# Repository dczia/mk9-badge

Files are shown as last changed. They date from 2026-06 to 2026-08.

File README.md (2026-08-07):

```
___  ____     _____  ______           _            
|  \/  | |   |  _  | | ___ \         | |           
| .  . | | __| |_| | | |_/ / __ _  __| | __ _  ___ 
| |\/| | |/ /\____ | | ___ \/ _` |/ _` |/ _` |/ _ \
| |  | |   < .___/ / | |_/ / (_| | (_| | (_| |  __/
\_|  |_/_|\_\\____/  \____/ \__,_|\__,_|\__, |\___|
                                         __/ |     
                                        |___/      
-------------------------------------------------
D C Z I A  ----------  2 0 2 6
```

DCZia Presents: The MK9 Badge

It blinks. It types. You can wear it around your neck and then set it on your desk and actually use it\*.

\* _Desk productivity not guaranteed. DCZia assumes no responsibility for keys accidentally sent during badge parties. Consult your keyboard layer documentation before operating heavy machinery._

---

## About

The **MK9** is a fully functional **3×3 mechanical macropad badge**. Nine real mechanical switches, per-key RGB lighting, ambient underglow, an accelerometer that actually does something interesting, SAO support, and CircuitPython firmware out of the box — all in a package sized to hang around your neck at DEF CON and survive the week.

---

## Specs

**Keys**
- 9× mechanical switches in a 3×3 grid — standard MX footprint, swap keycaps as you please
- Ships with translucent blue keycaps
- Full N-key rollover USB HID keyboard when plugged into a computer

**Lighting**
- 9× WS2812B per-key RGB LEDs — one under each switch
- 6× SK6812 side-firing LEDs — edge-mounted for ambient underglow out the sides

**Brains & Sensors**
- RP2040 microcontroller
- 3-axis accelerometer — tilt-reactive lighting, shake to change patterns
- 2× SAO connectors (standard 6-pin, I2C + 2 GPIO each) — expand with the badge add-on ecosystem

**Power & I/O**
- USB-C — power and data
- 3× AAA battery pack — run it untethered
- Power switch for battery mode
- Reset button + BOOTSEL button for easy firmware flashing

**Firmware**
- Ships with CircuitPython firmware
- QMK-compatible hardware — reflash and run it as a full QMK macropad

---

## What It Does Out of the Box

On boot: a rainbow diagonal wipe sweeps across the keys and backlights. Any keypress skips it.

Once running:
- Background light patterns cycle across all 15 LEDs — rainbow wave, breathing pulse, or sparkle
- Pressing a key sends a colour ripple expanding outward from that key through all the LEDs
- Tilt the badge to shift the colour palette; shake it to switch patterns
- Plug into a computer and it shows up as a numpad (7–9 / 4–6 / 1–3 layout)

---

## Repository

```
mk9-badge/
├── buildguide.md — badge assembly, flashing, and troubleshooting
├── hardware/   — KiCad design files, BOM, fabrication outputs
└── software/   — MicroPython firmware
```

- [Build Guide →](buildguide.md) — assembly, battery installation, flashing, and troubleshooting
- [Hardware →](hardware/README.md) — schematics, PCB layout, drill files, BOM
- [Software →](software/README.md) — firmware architecture, pinout, library requirements, flashing instructions

**Fabrication outputs**:
- [PCB layer plot](hardware/output/mk9-badge.pdf)
- [PTH drill map](hardware/output/mk9-badge-PTH-drl_map.pdf)
- [NPTH drill map](hardware/output/mk9-badge-NPTH-drl_map.pdf)

---

## Programming / Updating

The badge runs [CircuitPython](https://circuitpython.org). To update the firmware:

1. Hold **BOOTSEL** while plugging the badge into your computer — it mounts as `RPI-RP2`.
2. Drag the CircuitPython `.uf2` onto the drive. It reboots as `CIRCUITPY`.
3. Copy the `lib/` folder contents to `CIRCUITPY/lib/` (see [software/README.md](software/README.md) for the library list).
4. Copy all `.py` files from `software/` to the root of `CIRCUITPY`.

The badge restarts automatically. If it gets into a weird state, delete everything on `CIRCUITPY` and start fresh — it won't brick.

Want to run QMK instead? The hardware is fully compatible; QMK setup instructions will be posted separately.

**Recommended IDEs:** Visual Studio Code with the [CircuitPython extension](https://marketplace.visualstudio.com/items?itemName=ms-python.python), or [Thonny](https://thonny.org). A Commodore 64 with a serial adapter also works but is left as an exercise for the reader.

---

## Open Source

DCZia is committed to open source hardware and software. All design files and firmware are publicly available.

- **Live CAD (OnShape):** [View the design](https://cad.onshape.com/documents/36884624fbe35c16a5af61a7/w/233227193d278274727a44c3/e/ea987b4b53c4648fa3dc84b6)

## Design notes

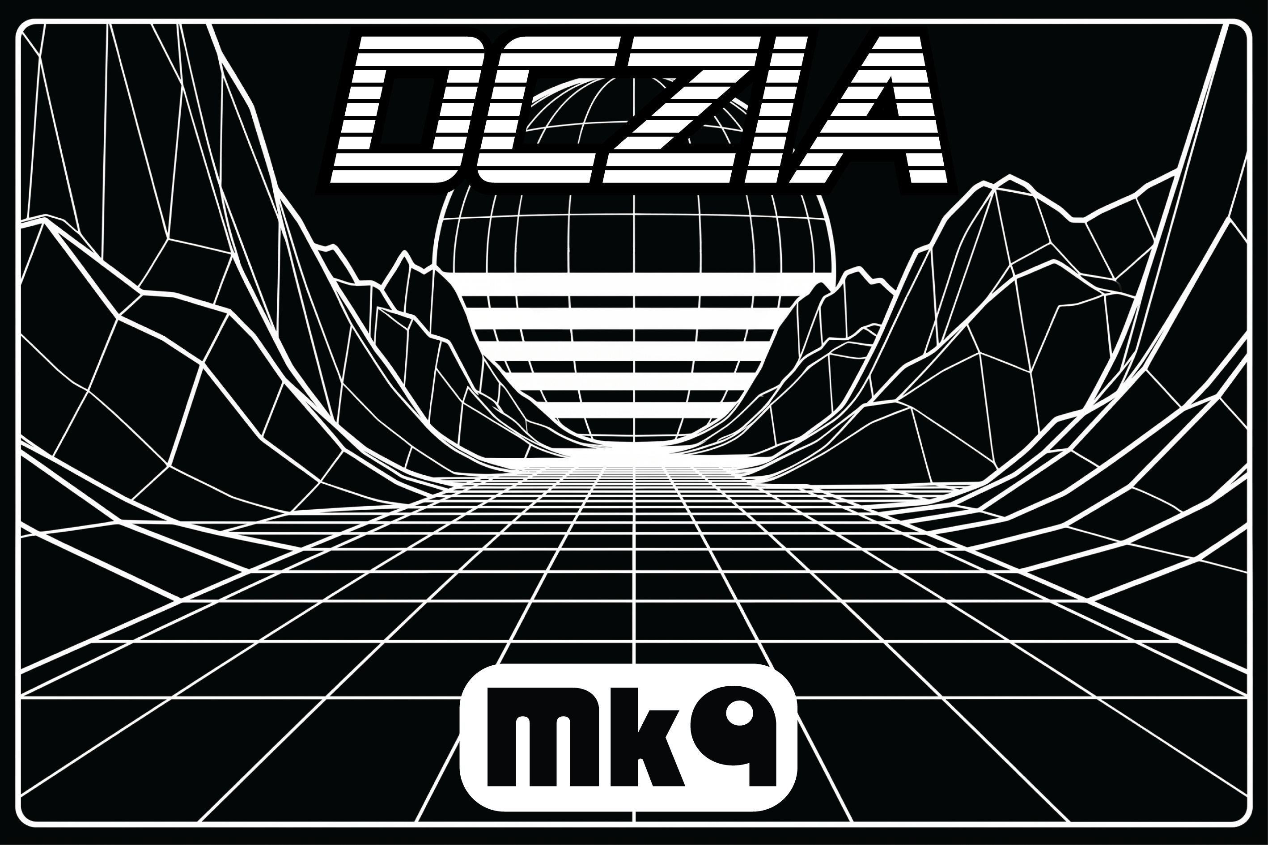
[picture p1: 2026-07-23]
hardware/images/SAO-Adapter.png

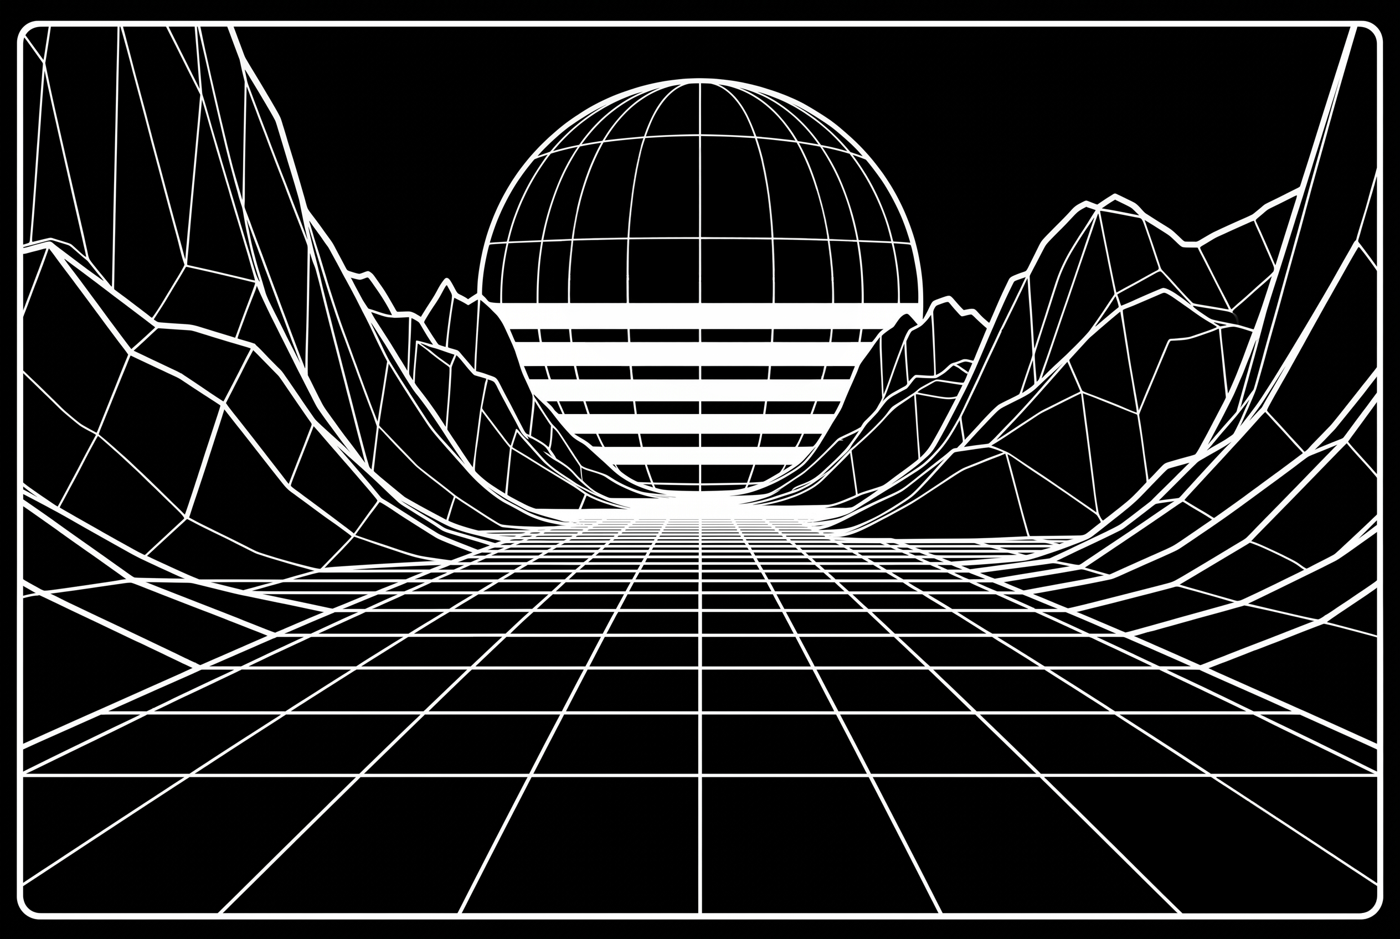
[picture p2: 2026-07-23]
hardware/images/cyberscape background.png

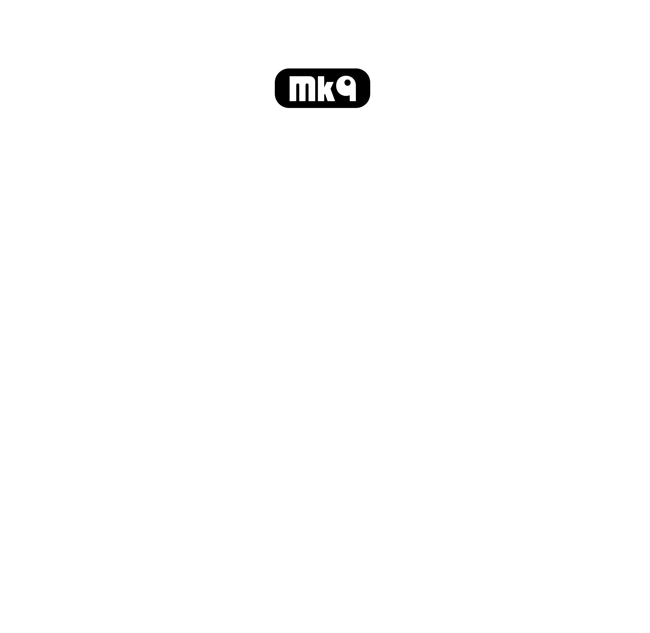
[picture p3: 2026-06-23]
hardware/images/Board_Silk.png

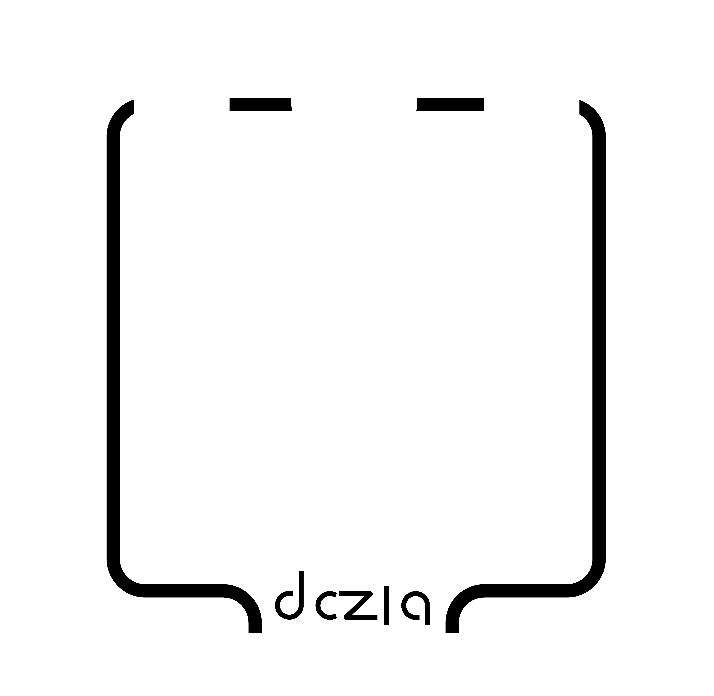
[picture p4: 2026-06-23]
hardware/images/Board_Copper.png

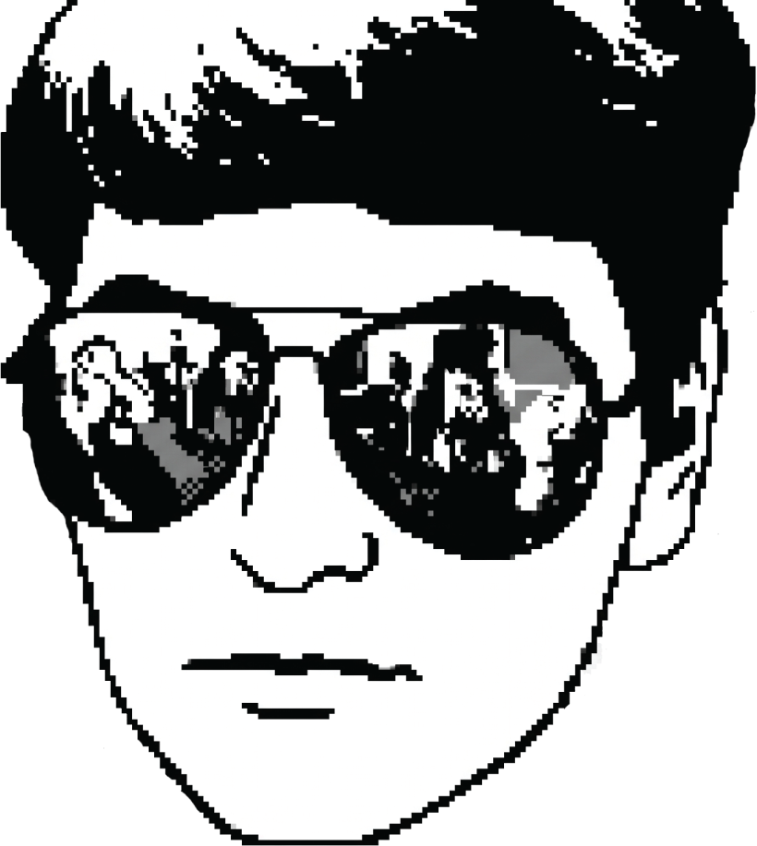
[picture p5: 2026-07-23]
hardware/images/bob.png

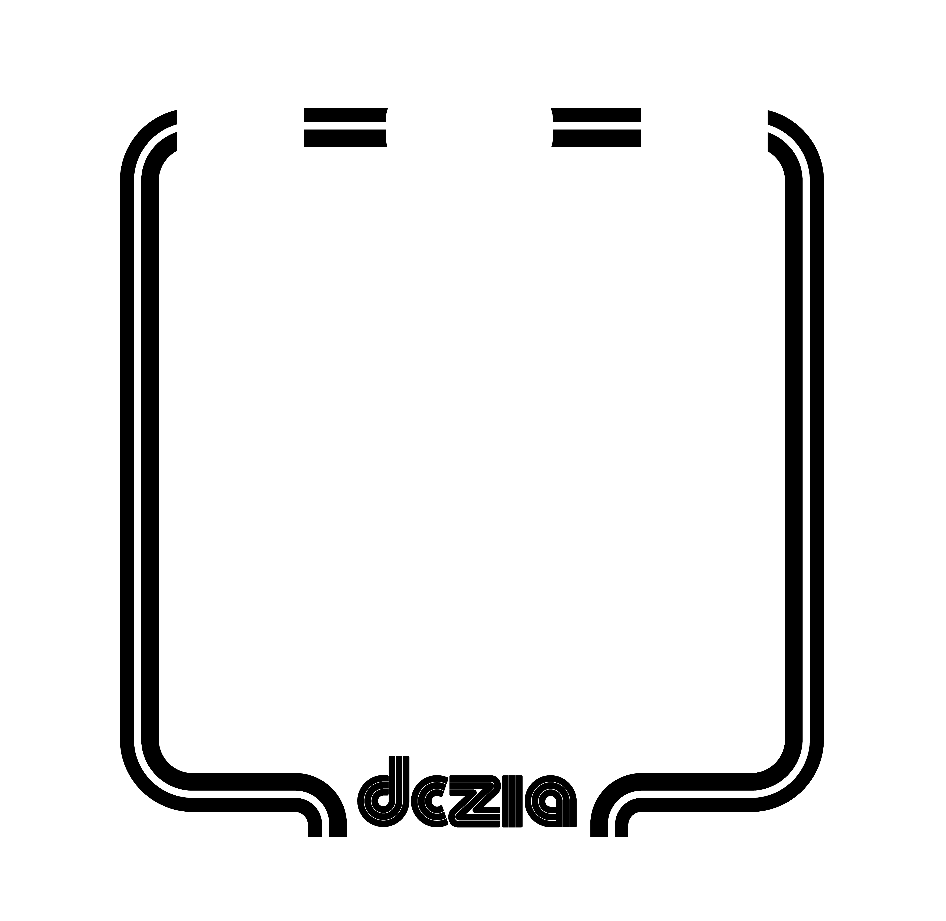
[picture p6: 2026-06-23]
hardware/images/Board_Mask.png

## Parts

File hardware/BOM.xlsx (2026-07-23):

Reference | Feeder | Value | Footprint | Part Number | Distributor | Distributor Part | Datasheet | Qty | Cost Each | Qty Ordered | QOH | Notes
C3,C5,C6,C8-C12,C15-C20 | 6 | 0.1uF | 0603 |  |  |  | ~ | 14 | 0.004 | 0 | 2500
C4,C7,C13,C14 | 7 | 1uF | 0603 |  |  |  | ~ | 4 | 0.004 | 0 | 3500
C1,C2 | 8 | 15pF | 0603 |  |  |  | ~ | 2 | 0.004 | 0 | 3500
D2-12 | 9 | D_Schottky | SOD-123 |  | Digikey | 3757-SS0540_R1_00001DKR-ND | https://www.panjit.com.tw/upload/datasheet/SS0520_SERIES.pdf | 2 | 0.11 | 0 | 2500
D13-21 | 23 | WS2812B | LED_SMD:LED_WS2812B_PLCC4_5.0x5.0mm_P3.2mm |  | Aliexpress | https://www.aliexpress.us/item/2251832628463811.html | https://cdn-shop.adafruit.com/datasheets/WS2812B.pdf | 9 | 0.07 | 0 | 2000
D22-27 | 22 | SK6812 |  |  | Aliexpress |  |  | 6 | 0.1 | 1000 | 0
D1 |  | TVS |  | SP0502BAHTG | Mouser | 576-SP0502BAHTG | https://www.littelfuse.com/assetdocs/tvs-diode-array-spasp050xba-lead-free-green-datasheet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 | 0 | 0.383 |  |  | Optional stuffing
J1 |  | USB-C | Connector_USB:USB_C_Receptacle_HCTL_HC-TYPE-C-16P-01A |  | Aliexpress | https://www.aliexpress.us/item/3256805324706422.html | https://www.lcsc.com/datasheet/lcsc_datasheet_2211161000_HCTL-HC-TYPE-C-16P-01A_C2894897.pdf | 1 | 0.19 | 150 | 100
R1,R7 | manual | 1k | 0603 |  |  |  | ~ | 2 | 0.001 | 0 | 4500
R6,R8 | 1 | 10k | 0603 |  |  |  | ~ | 2 | 0.001 | 0 | 4500
R2,R3 | 5 | 5.1k | 0603 |  |  |  | ~ | 2 | 0.001 | 0 | 4500
R4,R5 | 2 | 27R | 0603 |  |  |  | ~ | 2 | 0.001 | 0 | 4500
R9 | manual | 10R | 0603 |  |  |  | ~ | 1 | 0.001 | 0 | 4500
R10,R11 | 3 | 4.7k | 0603 |  |  |  |  | 2 | 0.001 | 5000 | 0
S1,S3 | after | SPST Push w/boss | Button_Switch_SMD:SW_SPST_EVQP7C | EVQ-P7C01P | Digikey | P16765CT-ND | https://api.pim.na.industrial.panasonic.com/file_stream/main/fileversion/245500 | 2 | 0.20204 | 300 | 0
S2 | after | SW_SPDT | lib_fp:SW_SPDT_CK-JS102011SAQN | JS102011SAQN | Digikey | 401-1999-1-ND | https://ckswitches.com/media/1422/js.pdf | 1 | 0.6032 | 150 | 0
S4-12 |  | CherryMX Blue |  |  | Aliexpress |  |  | 9 | 0.1 | 1000 | 0
U3 | 10 | NCP115ASN330T2G | Package_TO_SOT_SMD:SOT-23-5 | NCP115ASN330T2G | Digikey | NCP115ASN330T2G | https://www.onsemi.com/pdf/datasheet/ncp115-d.pdf | 1 | 0.0677 | 0 | 2500
U2 | 30 | RP2040 | Package_DFN_QFN:QFN-56-1EP_7x7mm_P0.4mm_EP3.2x3.2mm | SC0914(7) | Mouser | 358-SC09147 | https://datasheets.raspberrypi.com/rp2040/rp2040-datasheet.pdf | 1 | 0.8 | 0 | 1000
U4 | after | W25Q128JVSIM |  |  | Digikey | W25Q128JVSIM-ND | https://www.winbond.com/resource-files/W25Q128JV%20RevI%2008232021%20Plus.pdf | 1 | 2.51556 | 133 | 0
U1 | manual | GSDA213 | Kionix_LGA-12_2x2mm_P0.5mm_LayoutBorder2x4y | GSDA213 | Digikey | 4786-GSDA213TR-ND | https://goodarksemi.com/docs/datasheets/mems/GSDA213_SDS.pdf | 1 | 0.6595 | 150 | 0
X1,X2 |  | Badgelife_sao_connector_v169bis | lib_fp:Badgelife-Shitty-v1.69bis | VIRTUAL |  |  |  | 2
Y1 | manual | Crystal | Crystal:Crystal_SMD_3225-4Pin_3.2x2.5mm | ABM8-272-T3 | Digikey | 535-ABM8-272-T3DKR-ND | https://abracon.com/datasheets/ABM8-272-T3.pdf | 1 | 0.4085 | 150 | 0
 |  | Key caps |  |  |  |  |  | 9 | 0.19 | 1500
` |  | Battery boxes |  |  |  |  |  | 1 |  | 125
 |  | PCB |  |  |  |  |  | 1 |  | 200
 |  | Batteries |  |  | Amazon |  |  | 3 | 0.15 | 300
 |  | Badge Run, units | 120

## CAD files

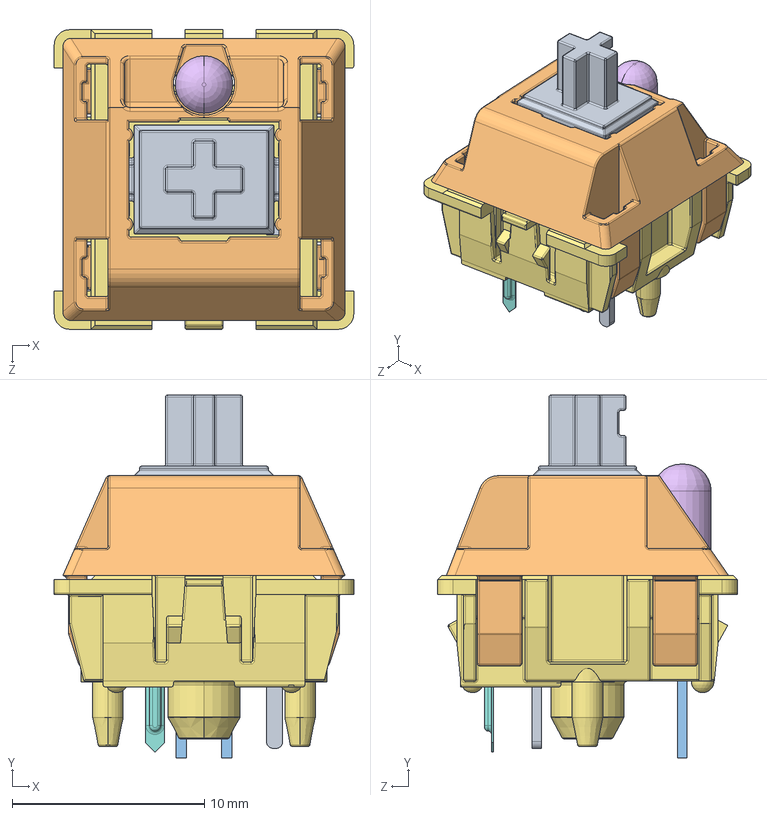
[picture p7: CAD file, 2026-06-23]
hardware/3d/MX.STEP
15.6 x 18.9 x 15.6 mm
MX ? ?? x 2
MX? ??LED
MX? ?? ??___
??___

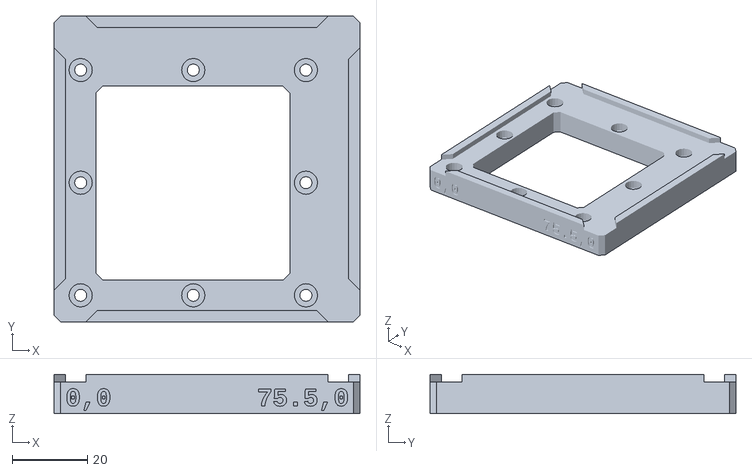
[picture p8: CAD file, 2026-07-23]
hardware/output/pcb_holder.stl
81.5 x 81.5 x 10.4

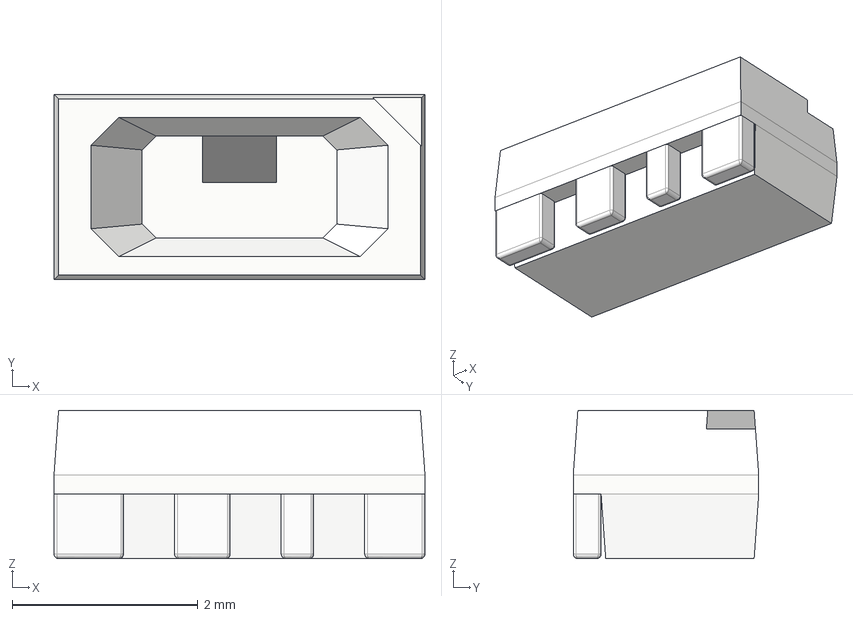
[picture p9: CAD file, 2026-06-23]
hardware/3d/sk6812side v0.step
4.00 x 2.00 x 1.60 mm

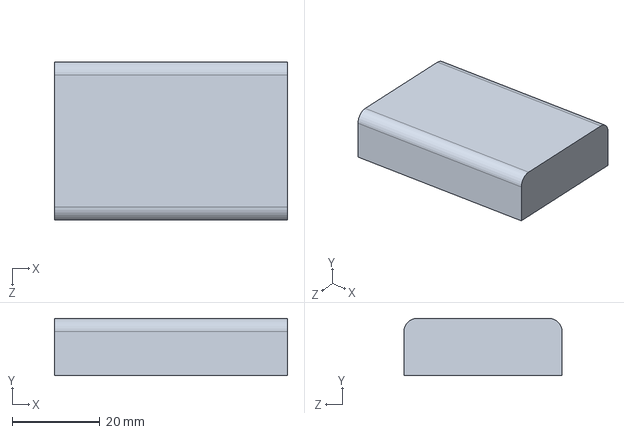
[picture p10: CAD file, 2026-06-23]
hardware/3d/3AAA Battery Box - Flying Leads.SLDPRT
53.0 x 13.0 x 36.0 mm

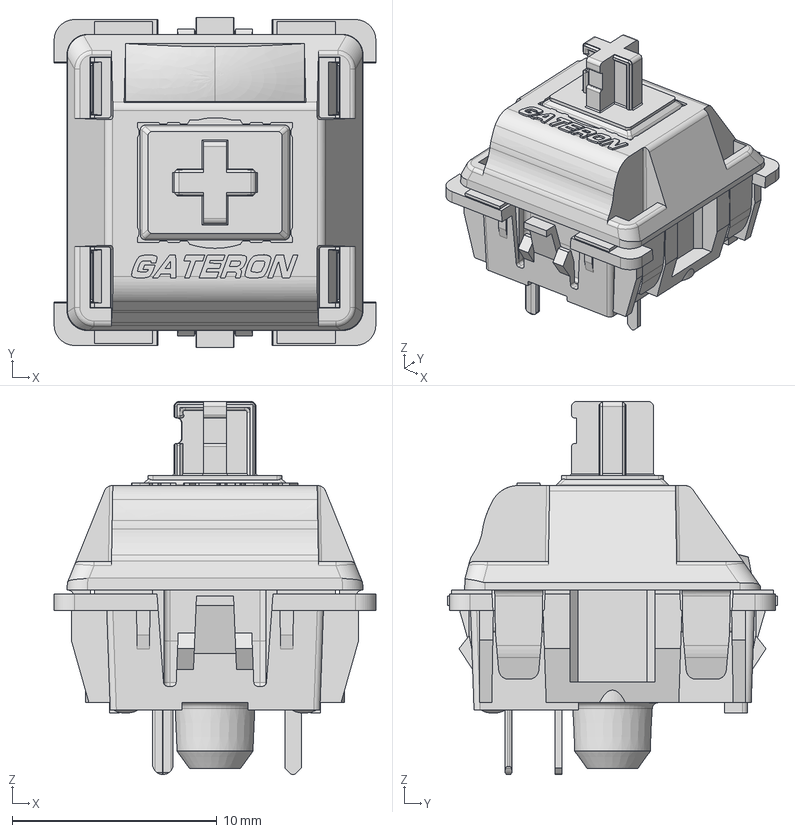
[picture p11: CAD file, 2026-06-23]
hardware/3d/G_PRO_3.0_Switch_KS-9E10B055NN-Y51.stp
15.7 x 16.1 x 18.2 mm

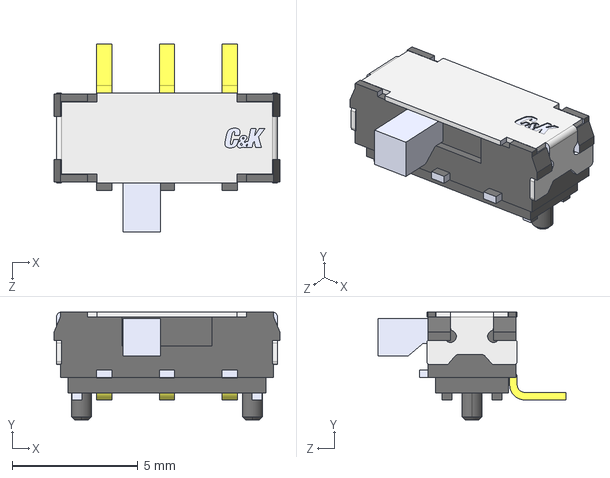
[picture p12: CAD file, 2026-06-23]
hardware/3d/JS102011SAQN.stp
9.00 x 4.30 x 7.50 mm

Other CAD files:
hardware/3d/G_PRO_3.0_Color.STEP

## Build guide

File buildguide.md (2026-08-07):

## TL;DR Instructions

1. Take the diffuser and back case off the badge using the included allen wrench
2. Solder on the keyswitches
3. Solder on the battery holder.
4. Reasseble the diffuser + case
5. Flash the badge with the u2f firmware from github / link can be found on www.dczia.net

## Intro

Thanks for purchasing the 2026 DCZia “mk9” badge! This badge is a throwback to our earlier keygrid badge from 2018. The badge features 9 mechanical MX style key switches (Gateron Blues), an accelerometer for sensing movement and adjusting the light patterns, and the badge can function as a usb keyboard / macro pad. By default the badge will output the keystrokes 1-9 like a num pad, but you can modify the code or flash QMK to use a full programmable macropad if you want. The badge is powered by an RPI 2040 microcontroller, with a 16mb flash module for expansion. An accelerometer is included as well.

## Building

The badge is shipped with the frosted diffuser, and back case pre installed. You will need to remove these pieces to safely solder on the keyswitches. Use the included allan key to disassemble the case.

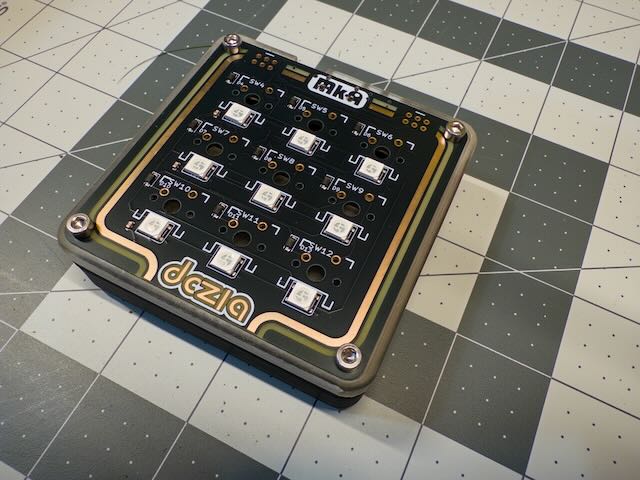
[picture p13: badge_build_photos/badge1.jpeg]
BuildPhoto1 Badge1


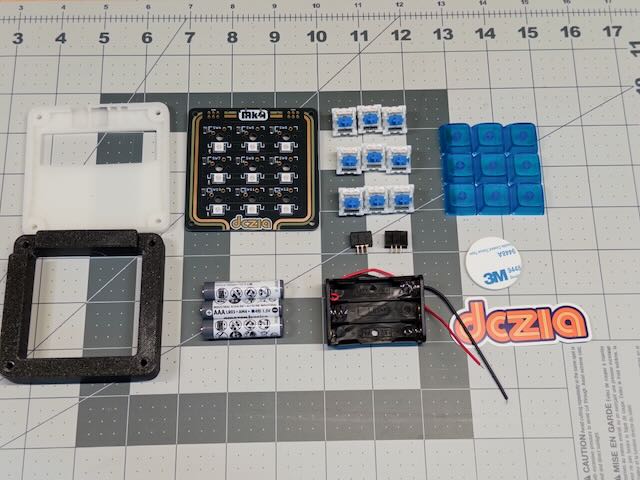
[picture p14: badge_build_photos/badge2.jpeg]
BuildPhoto2 Badge2


Now you can install one keyswitch, and solder it onto the board. Please go slow, and try to line up the switch carefully. Sometimes some tape can be useful to keep the switch in place. Solder on all 9 key switches.

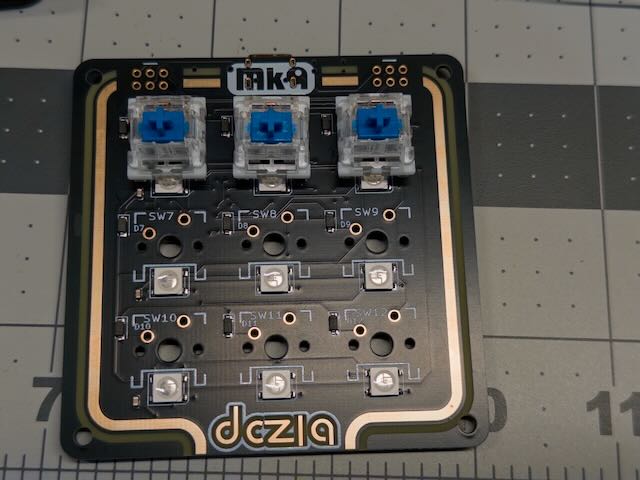
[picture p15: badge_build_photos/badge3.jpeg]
BuildPhoto3 Badge3

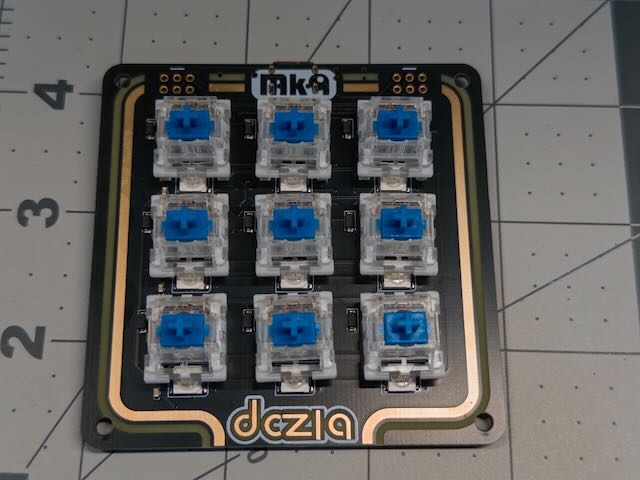
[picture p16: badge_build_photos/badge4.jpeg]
BuildPhoto4 Badge4

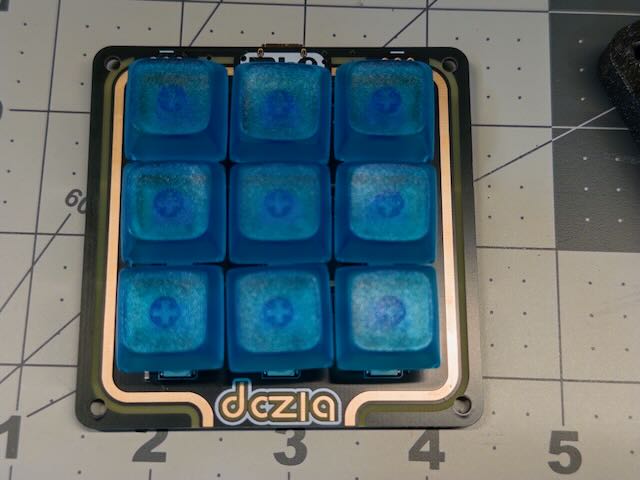
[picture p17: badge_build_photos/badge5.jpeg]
BuildPhoto5 Badge5


Reassemble the case, and gently screw it back together. 

Next solder on the battery pack. The red wire will go to the “+” pad on the back of the pcb, and the black wire to the “-” pad. The badge can be fully powered over USB C if you do not wish to attach the battery pack.

Next, using the round double sticky tape, apply it to the battery pack, and then stick it to the frosted diffuser. Press gently on the battery pack for about 15 seconds to make sure you have good adhesion.

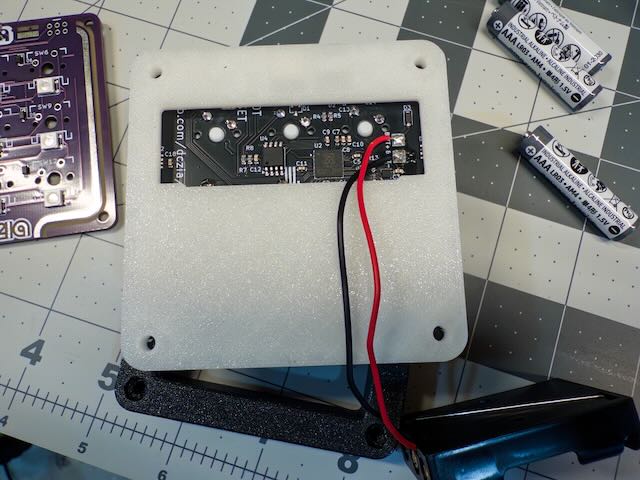
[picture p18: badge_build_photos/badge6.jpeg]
BuildPhoto5 Badge6


Finally install the batteries. The badge is pre-flashed with firmware and should be good to go!

Short press a key to see a light flash, long press a key to change the color theme. Tilt for accelerometer to affect the lights.

## Manual Flashing (Only if you want to update or write new code)

The badge is pre flashed, but you can run the script in the repo to flash the badge, or we will have a U2F uploaded which you can use as well.
Goto www.dczia.net, and click on the badge to be taken to the Github page for this project. Download the release which will have the source code, and a u2f file. Plug the badge into your computer and hold down the “Boot” button on the badge while plugging it in. You will need a pen or toothpick to press in the switch while plugging in the USB C cable. This will place the badge into bootloader mode. A usb drive should appear on your machine if you are using something common (Win / Mac) or if you don’t have an automounter and you are running linux, you can probably figure out how to mount the device as a drive. Drag the U2F file over to this drive. It will disconnected as soon as the transfer completes and the badge should reboot and begin showing some blinky lights!

## Badge Manual

Pressing any of the 9 keys will flash that keyswitch momentarily. Long pressing on one of the 9 keys will change the light themes. The accelerometer will allow you to tilt the badge in any of the light themes to affect the light pattern. Pressing any of the keys while plugged into usb c will output the keystroke 1-9. 

## Troubleshooting

*When i tilt my badge nothing happens?*

Some of the accelerometers may have gotten placed a bit off the pads. Find hamster for help, or if you have a hot air station, mask around the U1? part with kapton tape, and heat it gently while holding it down with some tweezers to realign to the pads. 

*Not all the keys are working?*

Re-check your solder connections on each switch

*The badge caught fire!*

The badge should only be powered by 3x AA batteries or USB-C. Please do not use car batteries, 120V AC, or small nuclear reactors to power the badge.

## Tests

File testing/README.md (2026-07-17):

# Hardware Tester

Self-contained hardware test fixture for the MK9 badge. Copy `code.py` to the root of `CIRCUITPY` (replacing the production firmware) to run the tests.

## What It Tests

### LEDs
All 15 LEDs (9 key + 6 backlight) cycle through **red → green → blue** continuously:
- Each color holds for **0.5 s**
- A directional wipe sweeps the next color across all LEDs over **0.5 s**
- Total: **1 second per color**

### Key Matrix
Press any key — its **LED fast-flashes red → green → blue** as long as the key is held, and is excluded from the background wipe until released. All 9 keys can be held simultaneously to verify N-key rollover. Every press/release is also logged to the serial console (`key N down` / `key N up`). Expected LED for each key:

```
key 0 (C0R0) → LED 0    key 1 (C1R0) → LED 1    key 2 (C2R0) → LED 2
key 3 (C0R1) → LED 3    key 4 (C1R1) → LED 4    key 5 (C2R1) → LED 5
key 6 (C0R2) → LED 6    key 7 (C1R2) → LED 7    key 8 (C2R2) → LED 8
```

### Accelerometer
The wipe always sweeps toward whichever edge is tilted down, decided when a new wipe starts:

| Axis reading | Meaning | Direction |
|---|---|---|
| X < 0 | Tilted left | Right → Left |
| X > 0 | Tilted right | Left → Right |
| Y < 0 | Top edge down | Bottom → Top |
| Y > 0 | Bottom edge down | Top → Bottom |
| Flat (both axes < 1 m/s²) | — | Holds last direction |

Tilt the badge and watch the wipe direction change on the next colour transition.

If the accelerometer library/sensor is missing at boot, or a read fails at runtime, the tester stops the colour-cycle test and instead flashes all LEDs solid **red, red, red, blue, green** (repeated) at 0.3 s/color, with no wipe, as a fault indicator.

### Serial Output
Connect a serial terminal to see:
- A boot message reporting whether the accelerometer initialized OK
- Accelerometer X/Y/Z readings printed once per second (or `accel: not available` if the sensor is down)
- `key N down` / `key N up` for every key press/release

## Libraries Required

Beyond CircuitPython built-ins (`board`, `busio`, `time`, `keypad`), copy these from the Adafruit CircuitPython Bundle into `lib/`:

| Library | Notes |
|---|---|
| `neopixel.mpy` | LED driver |
| `adafruit_msa3xx.mpy` | Accelerometer driver |
| `adafruit_bus_device/` | I2C helper — dependency of `adafruit_msa3xx` |
| `adafruit_register/` | Register access helper — dependency of `adafruit_msa3xx` |

If the accelerometer library is missing or the sensor doesn't respond, the tester falls back gracefully — LEDs and keys still work, but the LEDs switch to the red/red/red/blue/green fault-flash pattern described above instead of the normal colour cycle.

## Restoring Production Firmware

After testing, copy all files from `software/` back to the root of `CIRCUITPY` (including `boot.py`).

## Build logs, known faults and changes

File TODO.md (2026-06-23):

# MK9 Badge Hardware TODO

- [X] Add pull-up resistors on I2C lines
- [ ] Consider pullups for the accel
- [X] Add reset circuit
- [ ] Verify SK6812 pinouts
- [ ] Update flash footprint
- [ ] Update SPST footprints
- [X] Sidefire footprints
- [ ] libfp
- [ ] artwork
- [ ] order 4.7k resistors 0603

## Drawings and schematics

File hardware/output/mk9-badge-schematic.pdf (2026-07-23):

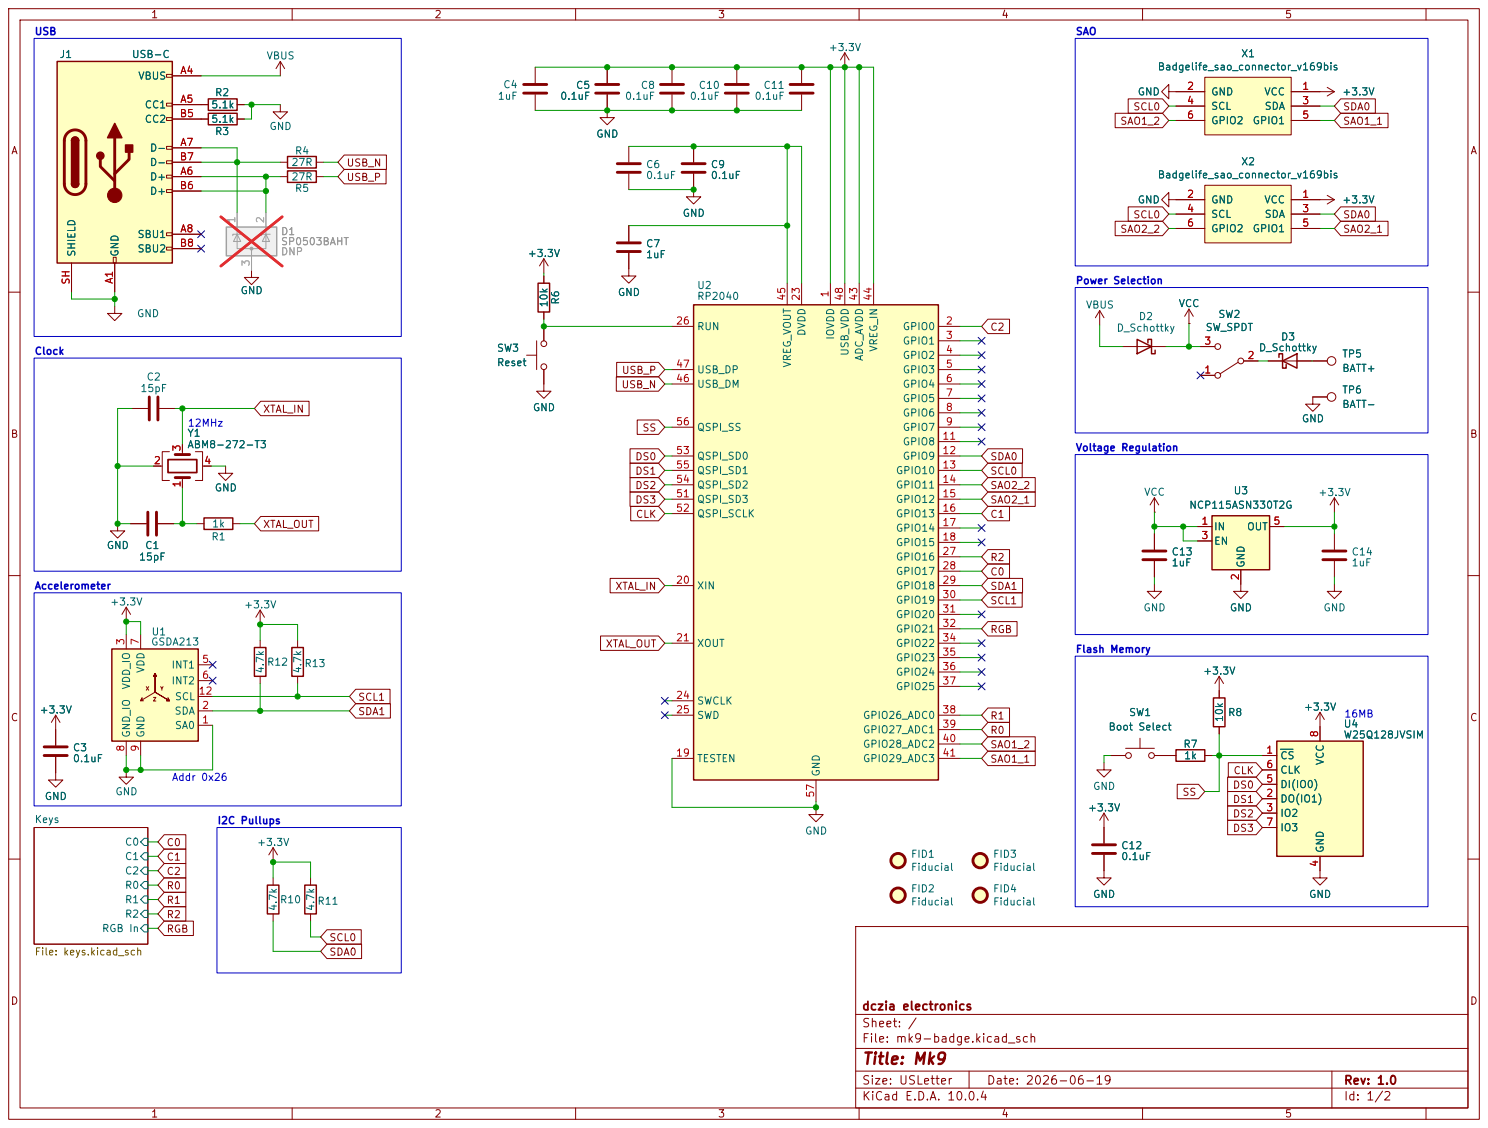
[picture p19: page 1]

Size: USLetter | Rev: 1.0
KiCad E.D.A. 10.0.4 | Id: 1/2

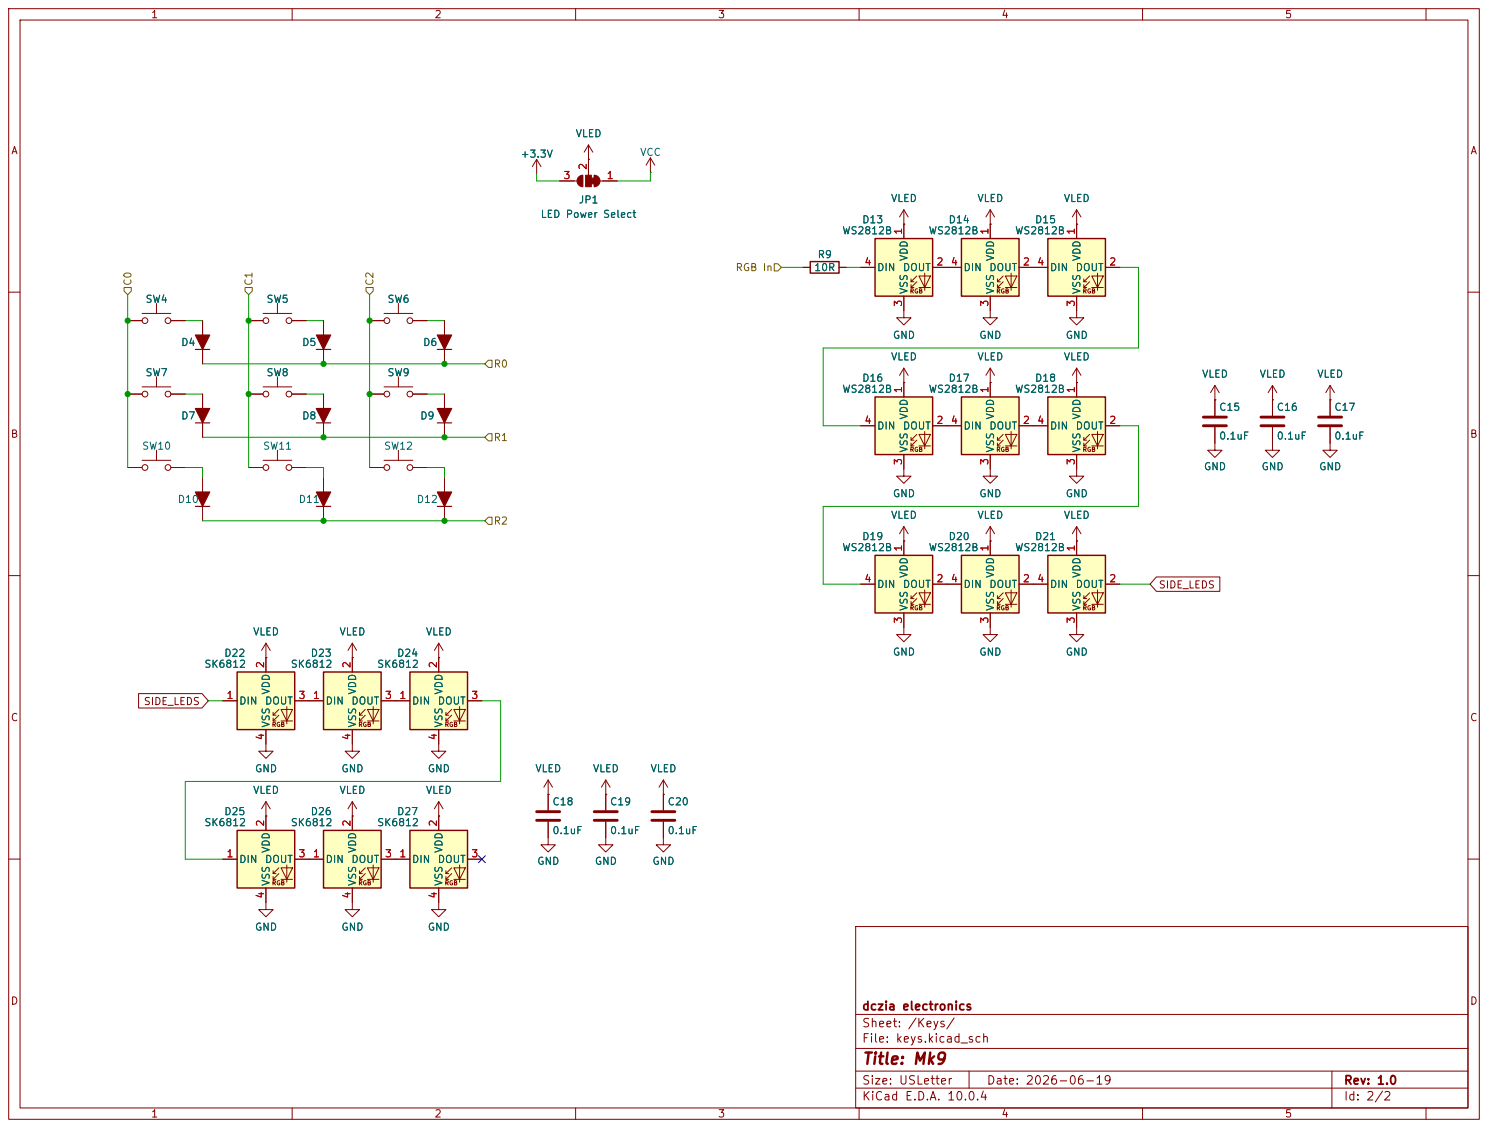
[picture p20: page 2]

Size: USLetter | Rev: 1.0
KiCad E.D.A. 10.0.4 | Id: 2/2

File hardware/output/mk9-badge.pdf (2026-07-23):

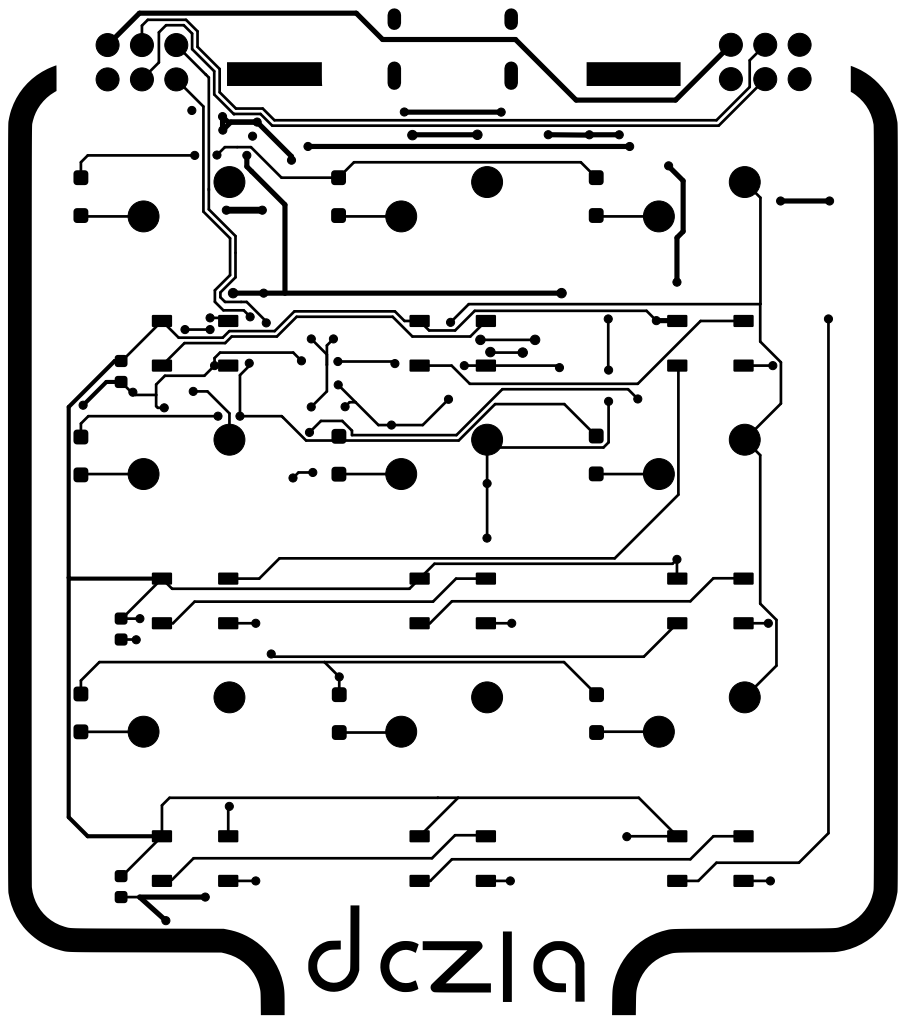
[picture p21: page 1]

Size: USLetter | Rev: 1.0
KiCad E.D.A. 10.0.4 | Id: 1/11

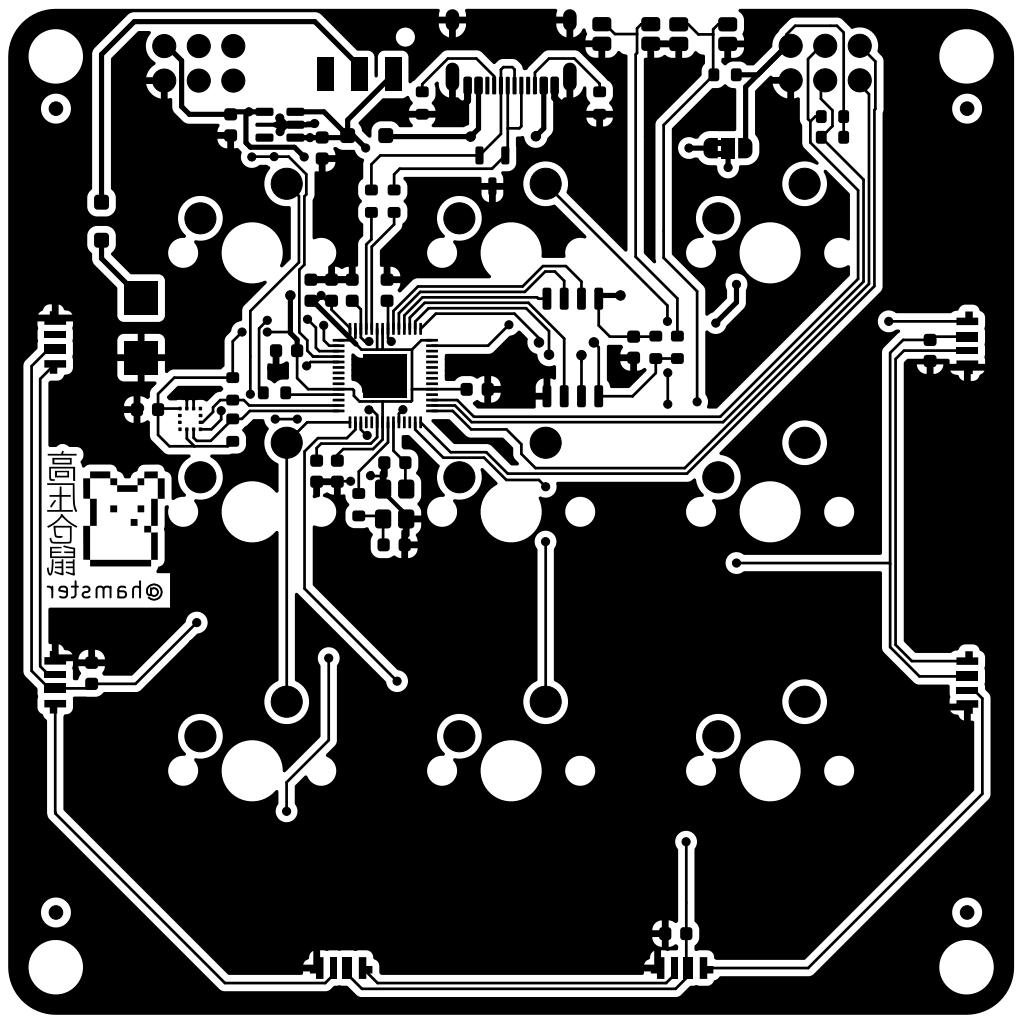
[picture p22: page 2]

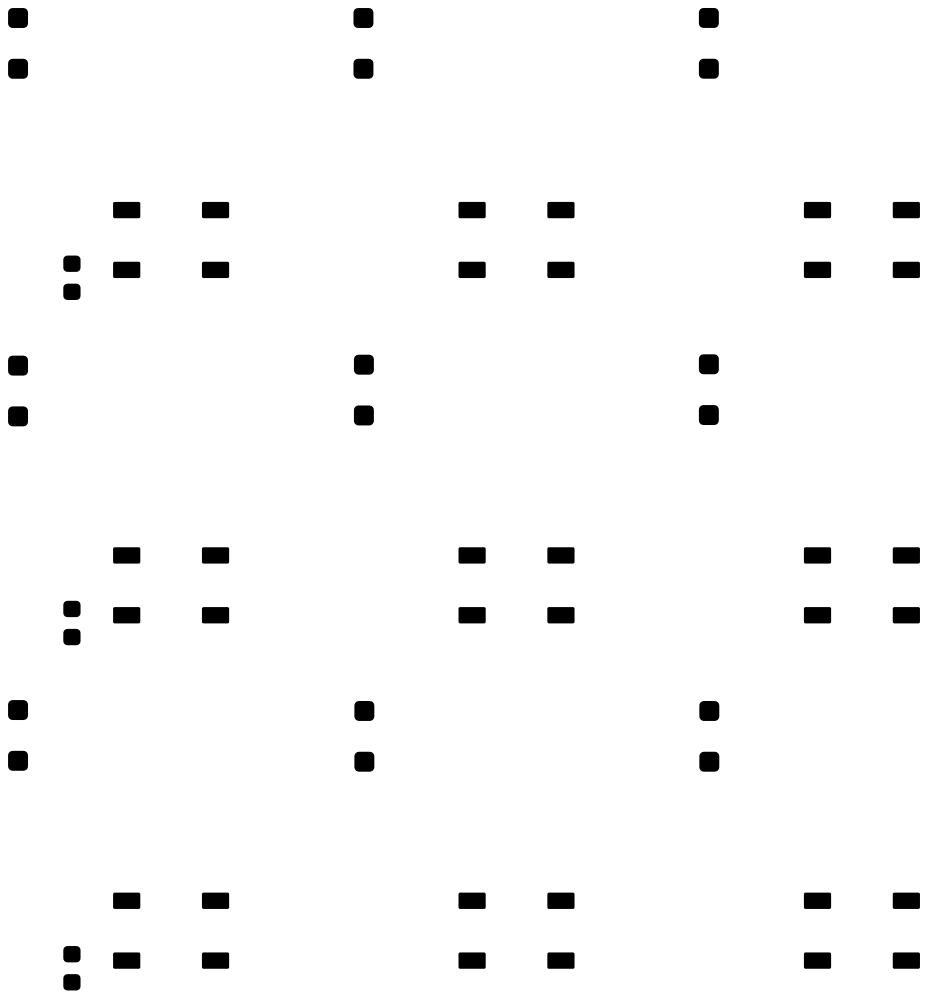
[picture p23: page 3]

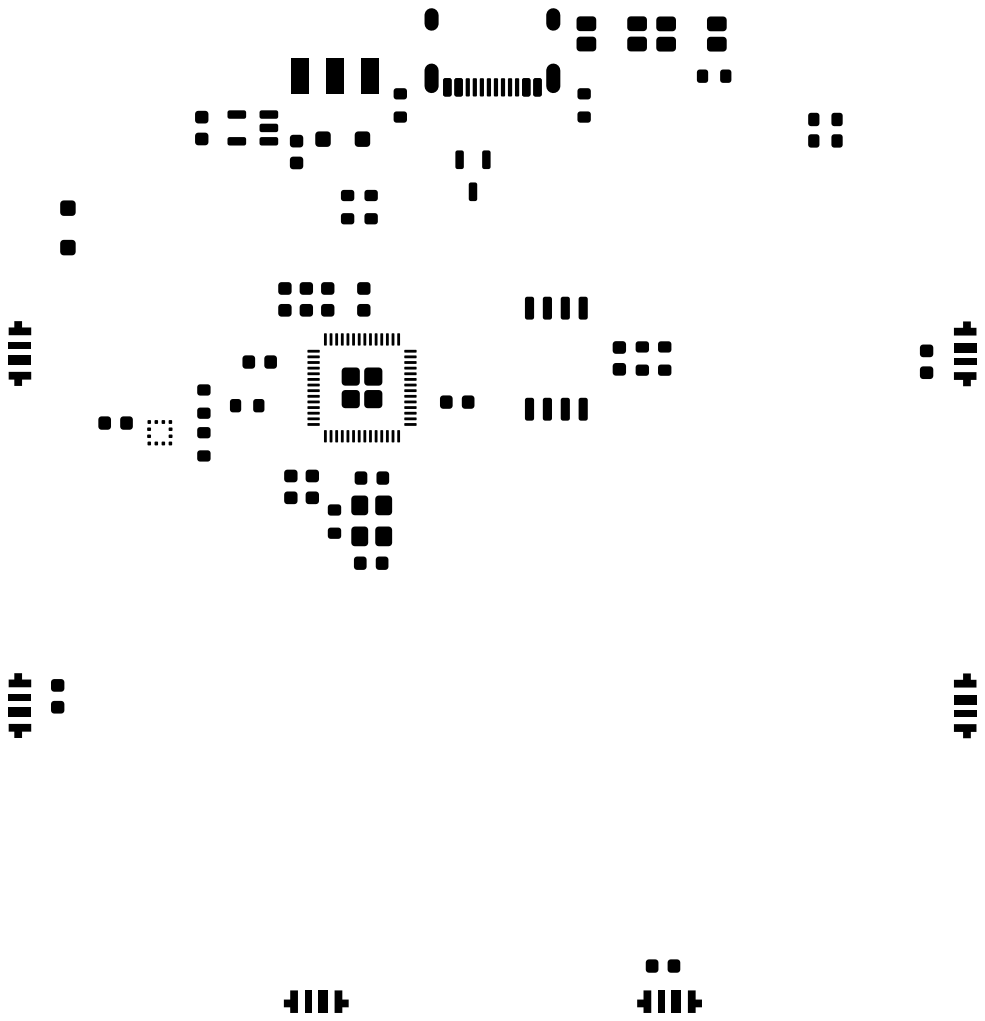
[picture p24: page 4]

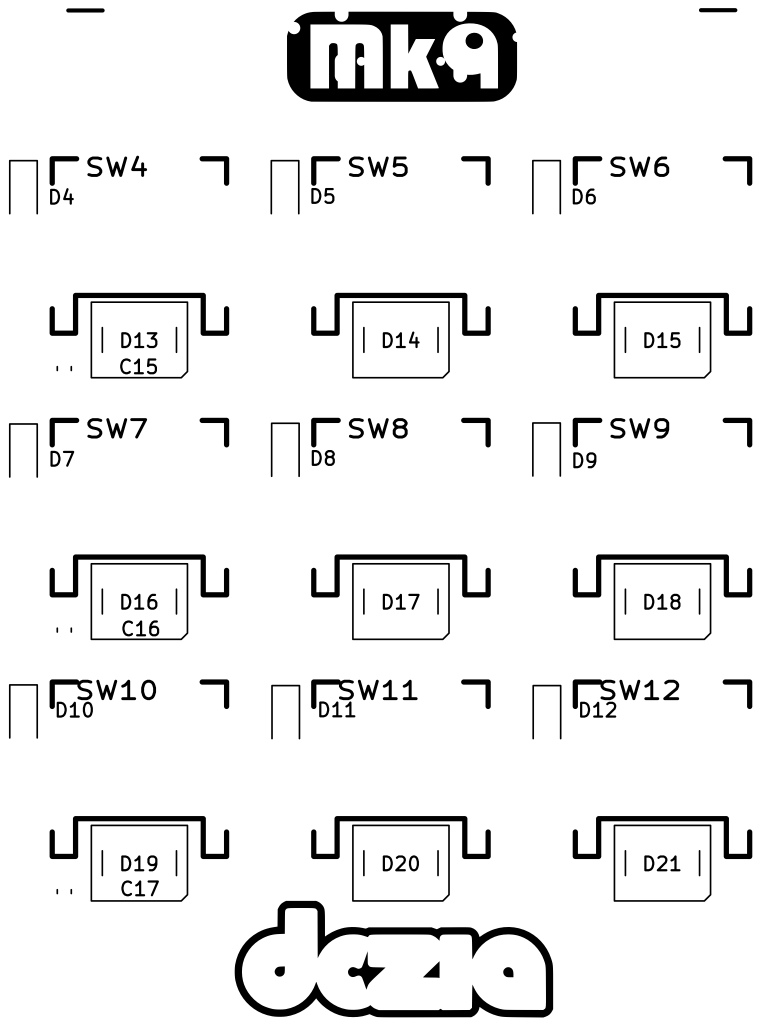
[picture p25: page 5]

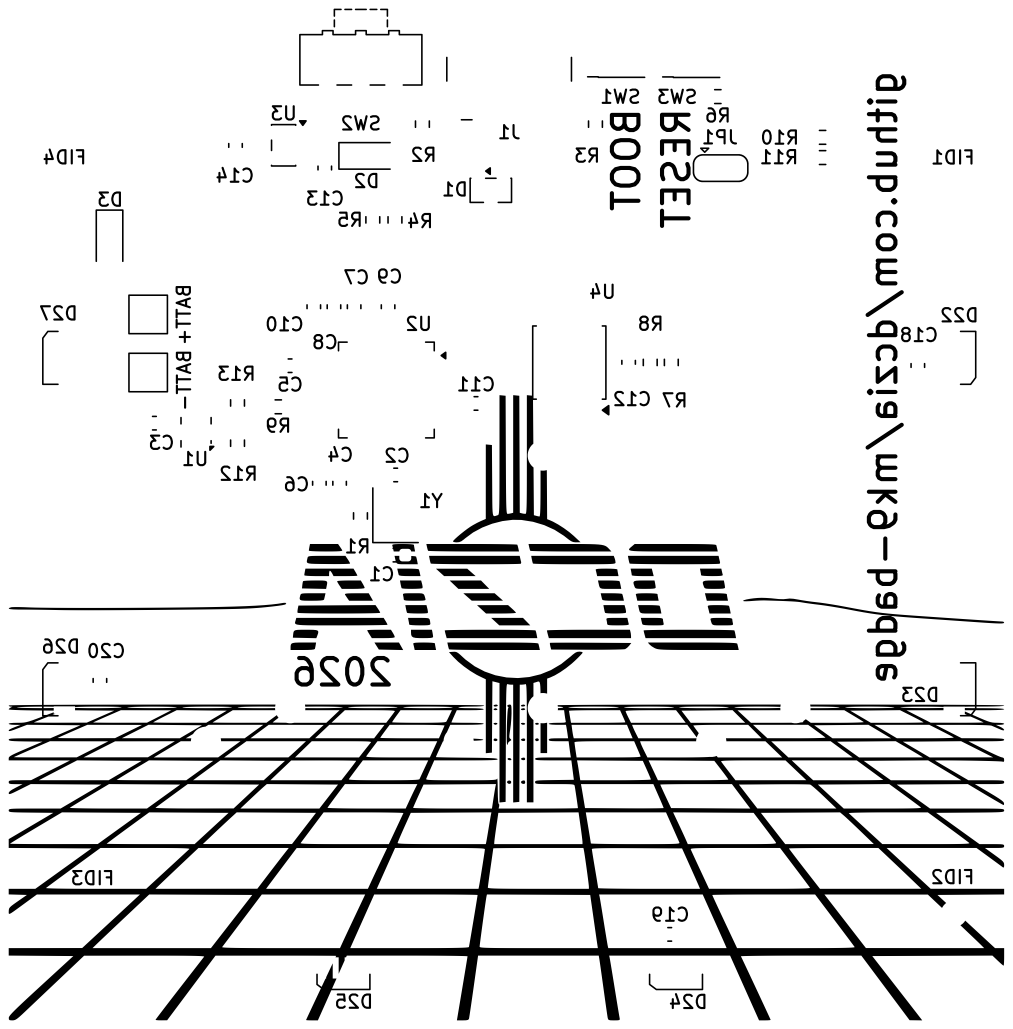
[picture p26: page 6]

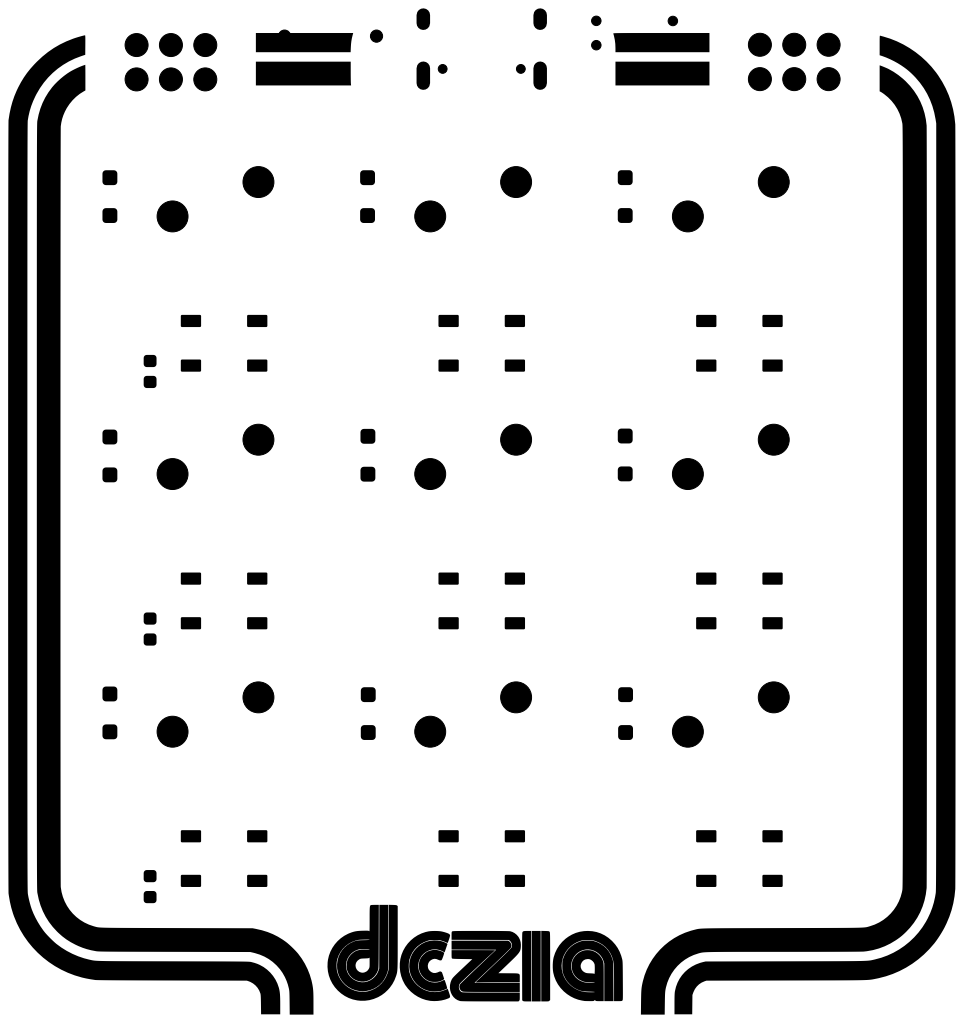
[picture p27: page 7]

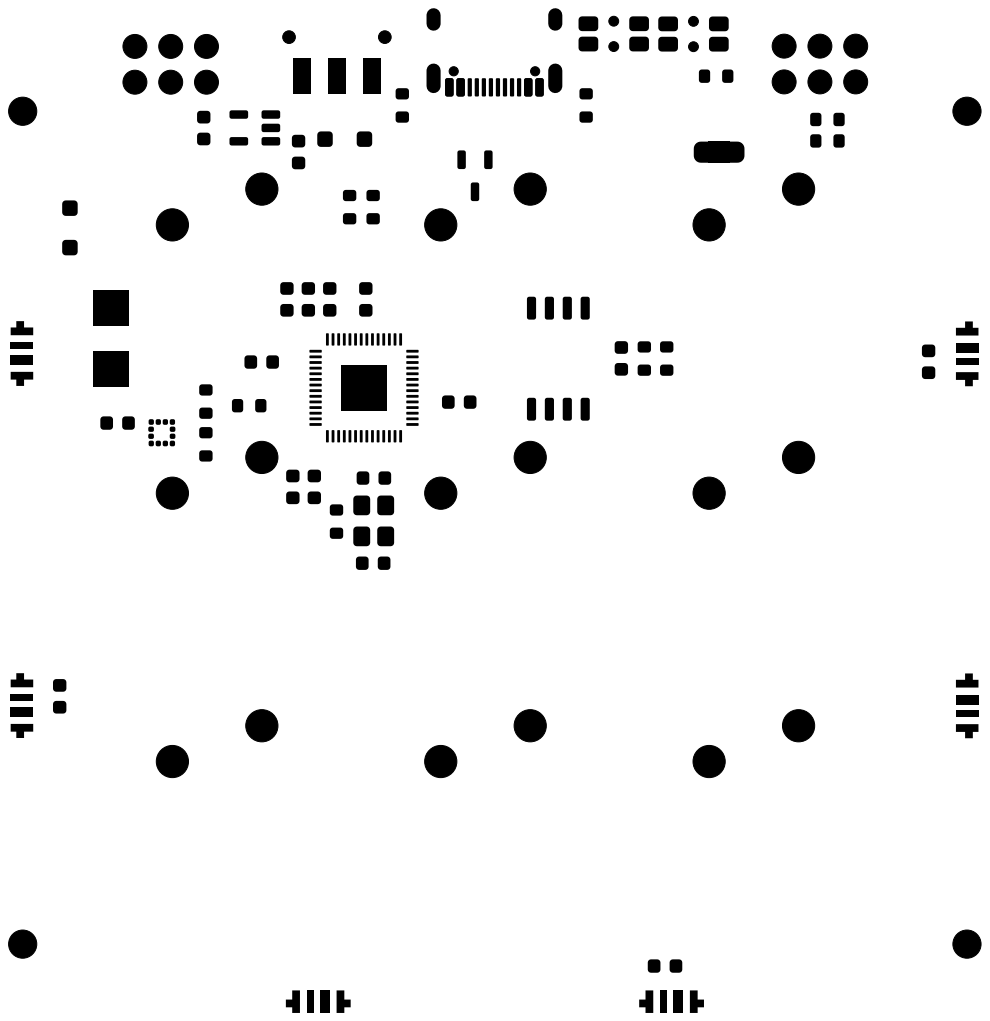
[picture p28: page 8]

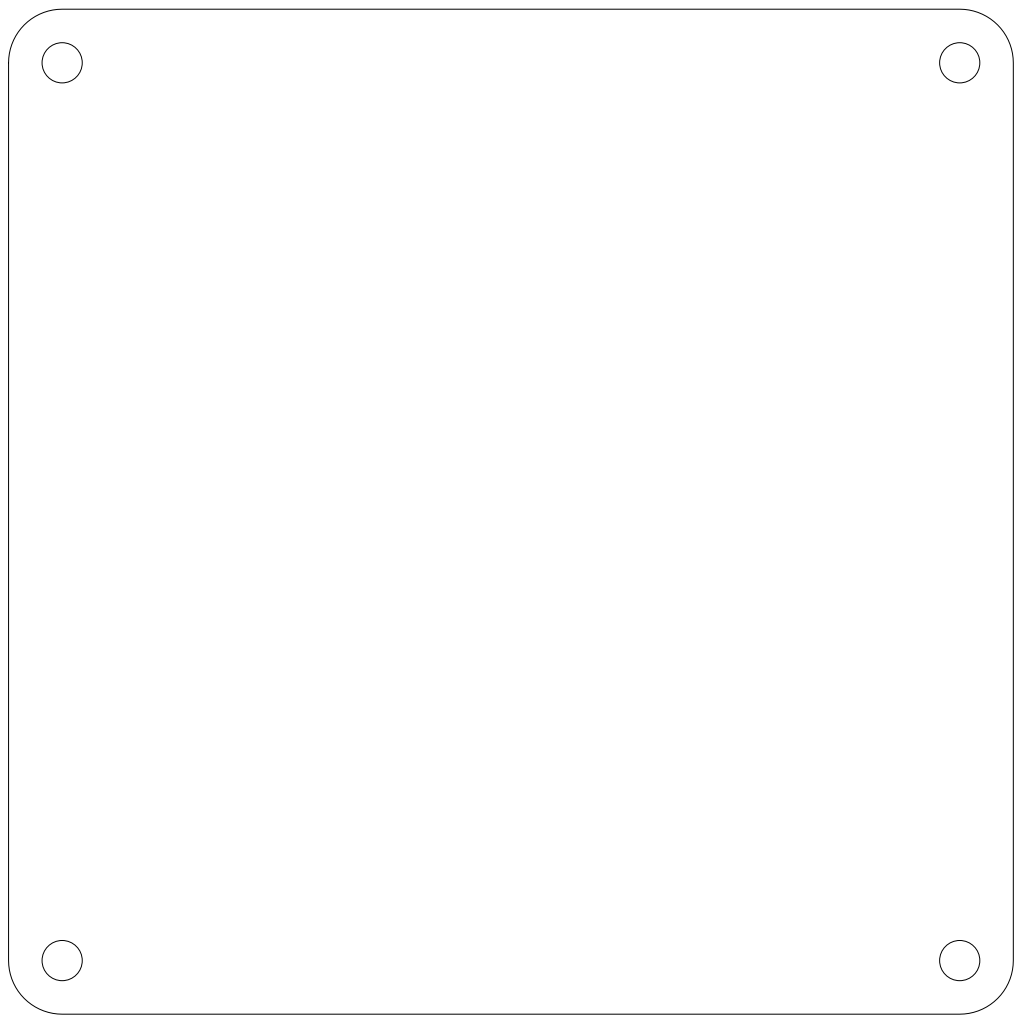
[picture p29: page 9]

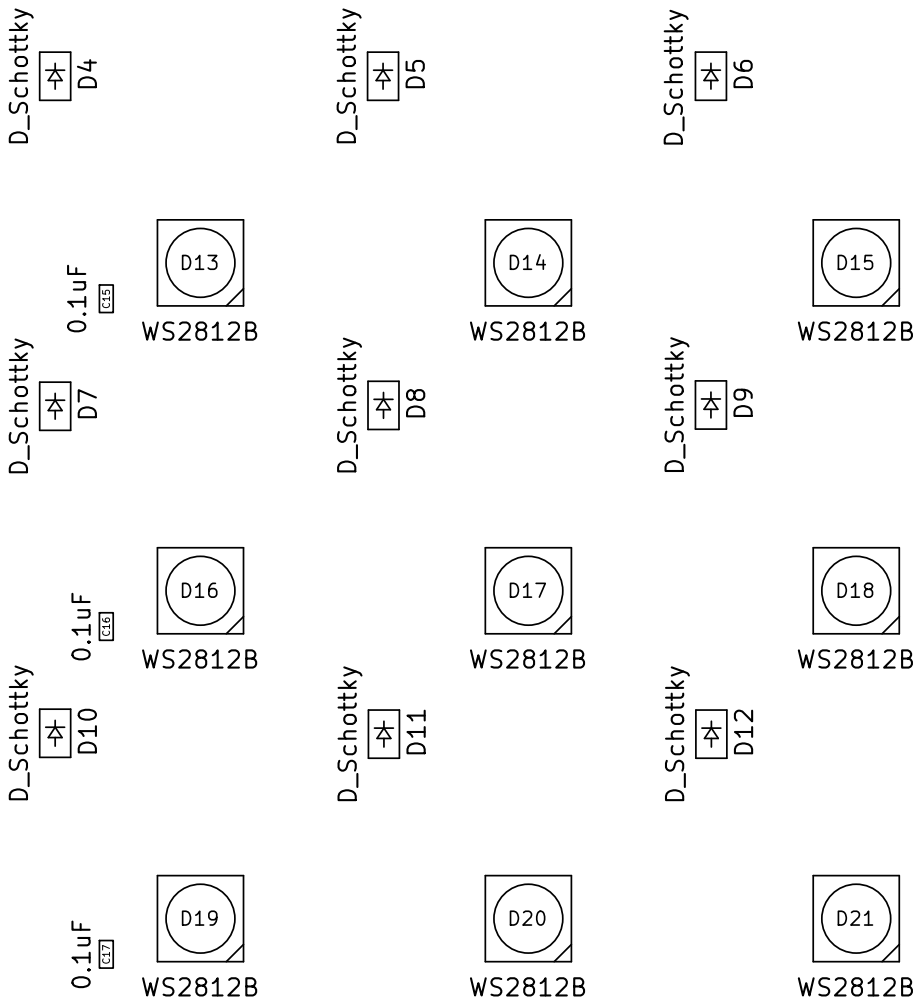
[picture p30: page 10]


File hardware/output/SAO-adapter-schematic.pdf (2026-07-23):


Size: USLetter | Rev: 1.0
KiCad E.D.A. 10.0.4 | Id: 1/1

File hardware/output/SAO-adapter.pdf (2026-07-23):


Size: USLetter | Rev: 1.0
KiCad E.D.A. 10.0.4 | Id: 1/9









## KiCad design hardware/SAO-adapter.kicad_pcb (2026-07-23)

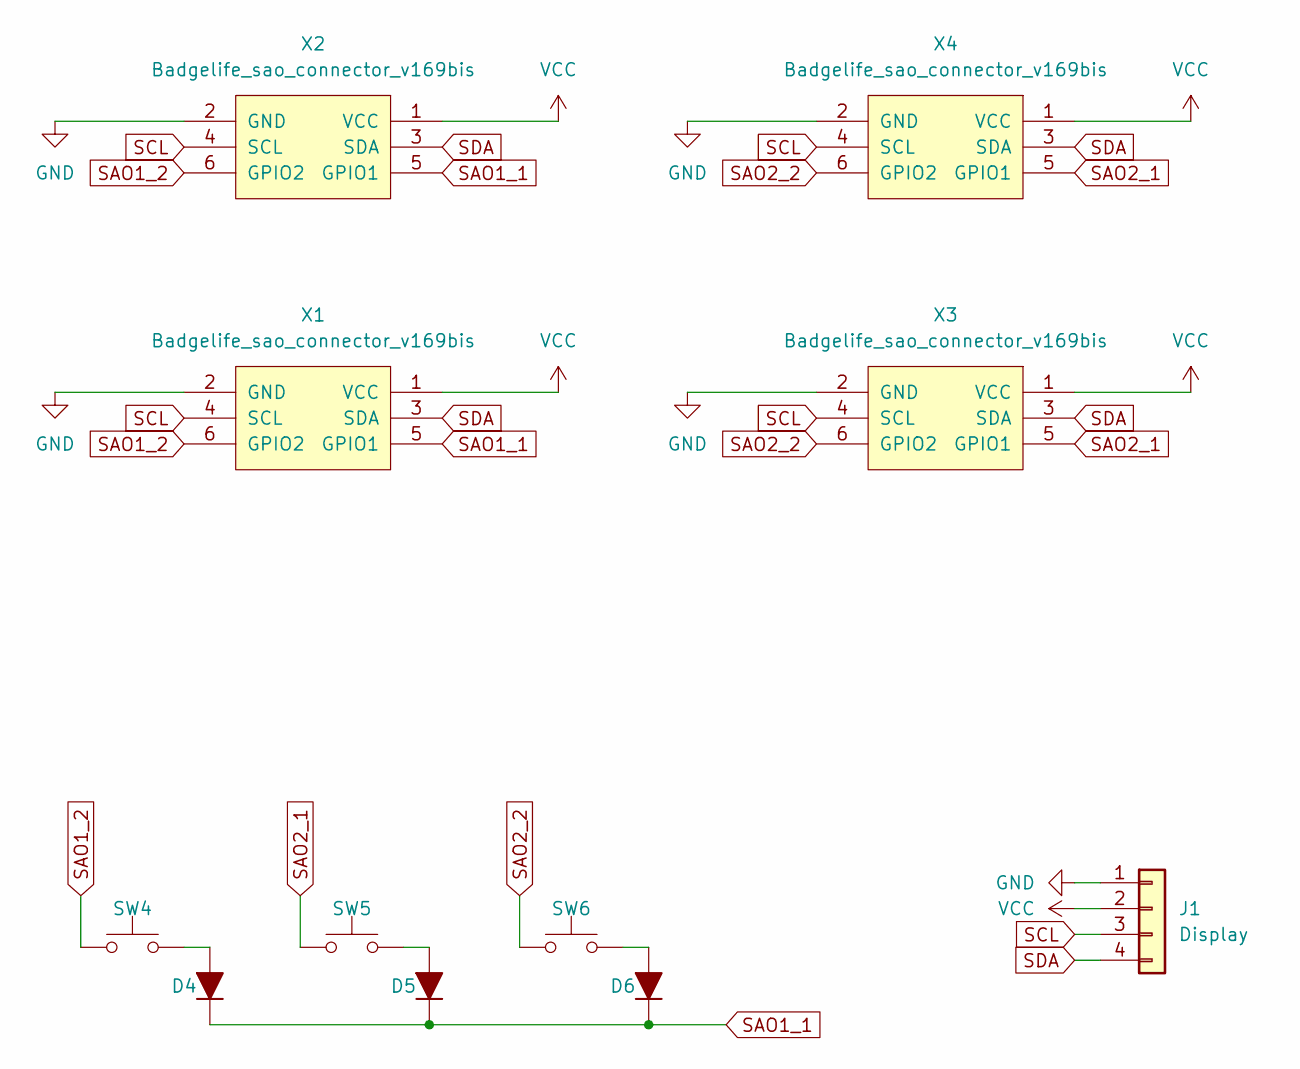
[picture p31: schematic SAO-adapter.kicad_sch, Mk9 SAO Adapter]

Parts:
D4, D5, D6: D_Schottky; D_SOD-123F
J1: Display; PinHeader_1x04_P2.54mm_Vertical
SW4, SW5, SW6: SW_Push; MX-Alps-Choc-1U-NoFrontMask
X1, X3: Badgelife_sao_connector_v169bis; Badgelife-Shitty-v1.69bis-No-Silk
X2, X4: Badgelife_sao_connector_v169bis; Badgelife-Shitty-v1.69bis-Minimal-Front

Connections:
GND: J1.1, X1.2 (GND), X2.2 (GND), X3.2 (GND), X4.2 (GND)
unnamed: D4.2 (A), SW4.2
unnamed: D5.2 (A), SW5.2
unnamed: D6.2 (A), SW6.2
SAO1_1: D4.1 (K), D5.1 (K), D6.1 (K), X1.5 (GPIO1), X2.5 (GPIO1)
SAO1_2: SW4.1, X1.6 (GPIO2), X2.6 (GPIO2)
SAO2_1: SW5.1, X3.5 (GPIO1), X4.5 (GPIO1)
SAO2_2: SW6.1, X3.6 (GPIO2), X4.6 (GPIO2)
SCL: J1.3, X1.4 (SCL), X2.4 (SCL), X3.4 (SCL), X4.4 (SCL)
SDA: J1.4, X1.3 (SDA), X2.3 (SDA), X3.3 (SDA), X4.3 (SDA)
VCC: J1.2, X1.1 (VCC), X2.1 (VCC), X3.1 (VCC), X4.1 (VCC)

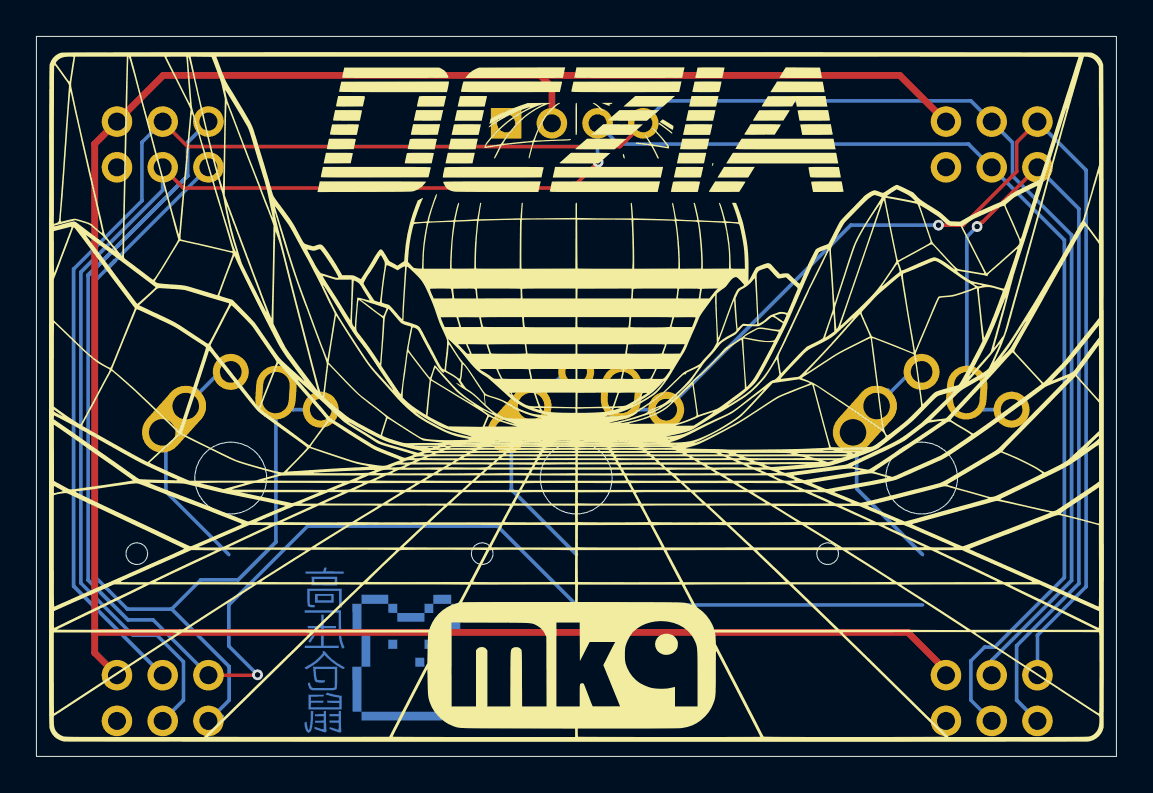
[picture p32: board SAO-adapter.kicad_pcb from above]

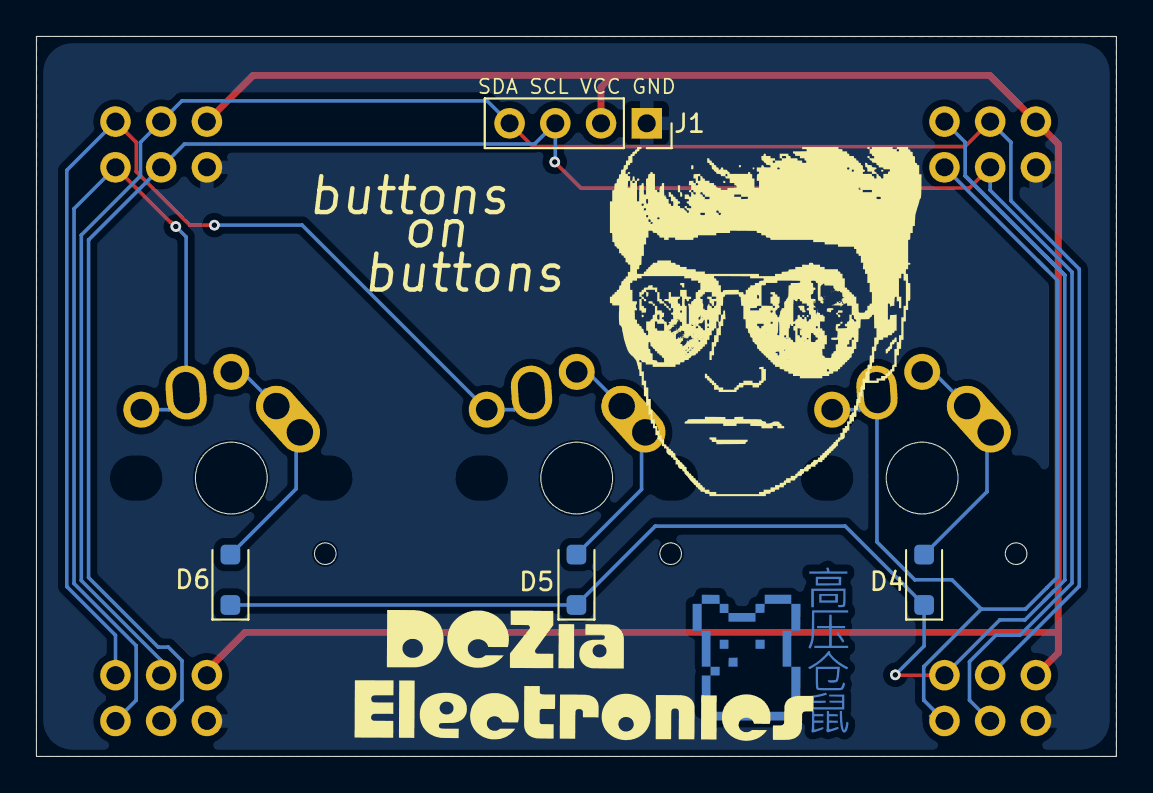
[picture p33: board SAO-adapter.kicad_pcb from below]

Board: 2 copper layers, 60.0 x 40.0 mm, 11 parts (3 on the bottom side), 11 nets.

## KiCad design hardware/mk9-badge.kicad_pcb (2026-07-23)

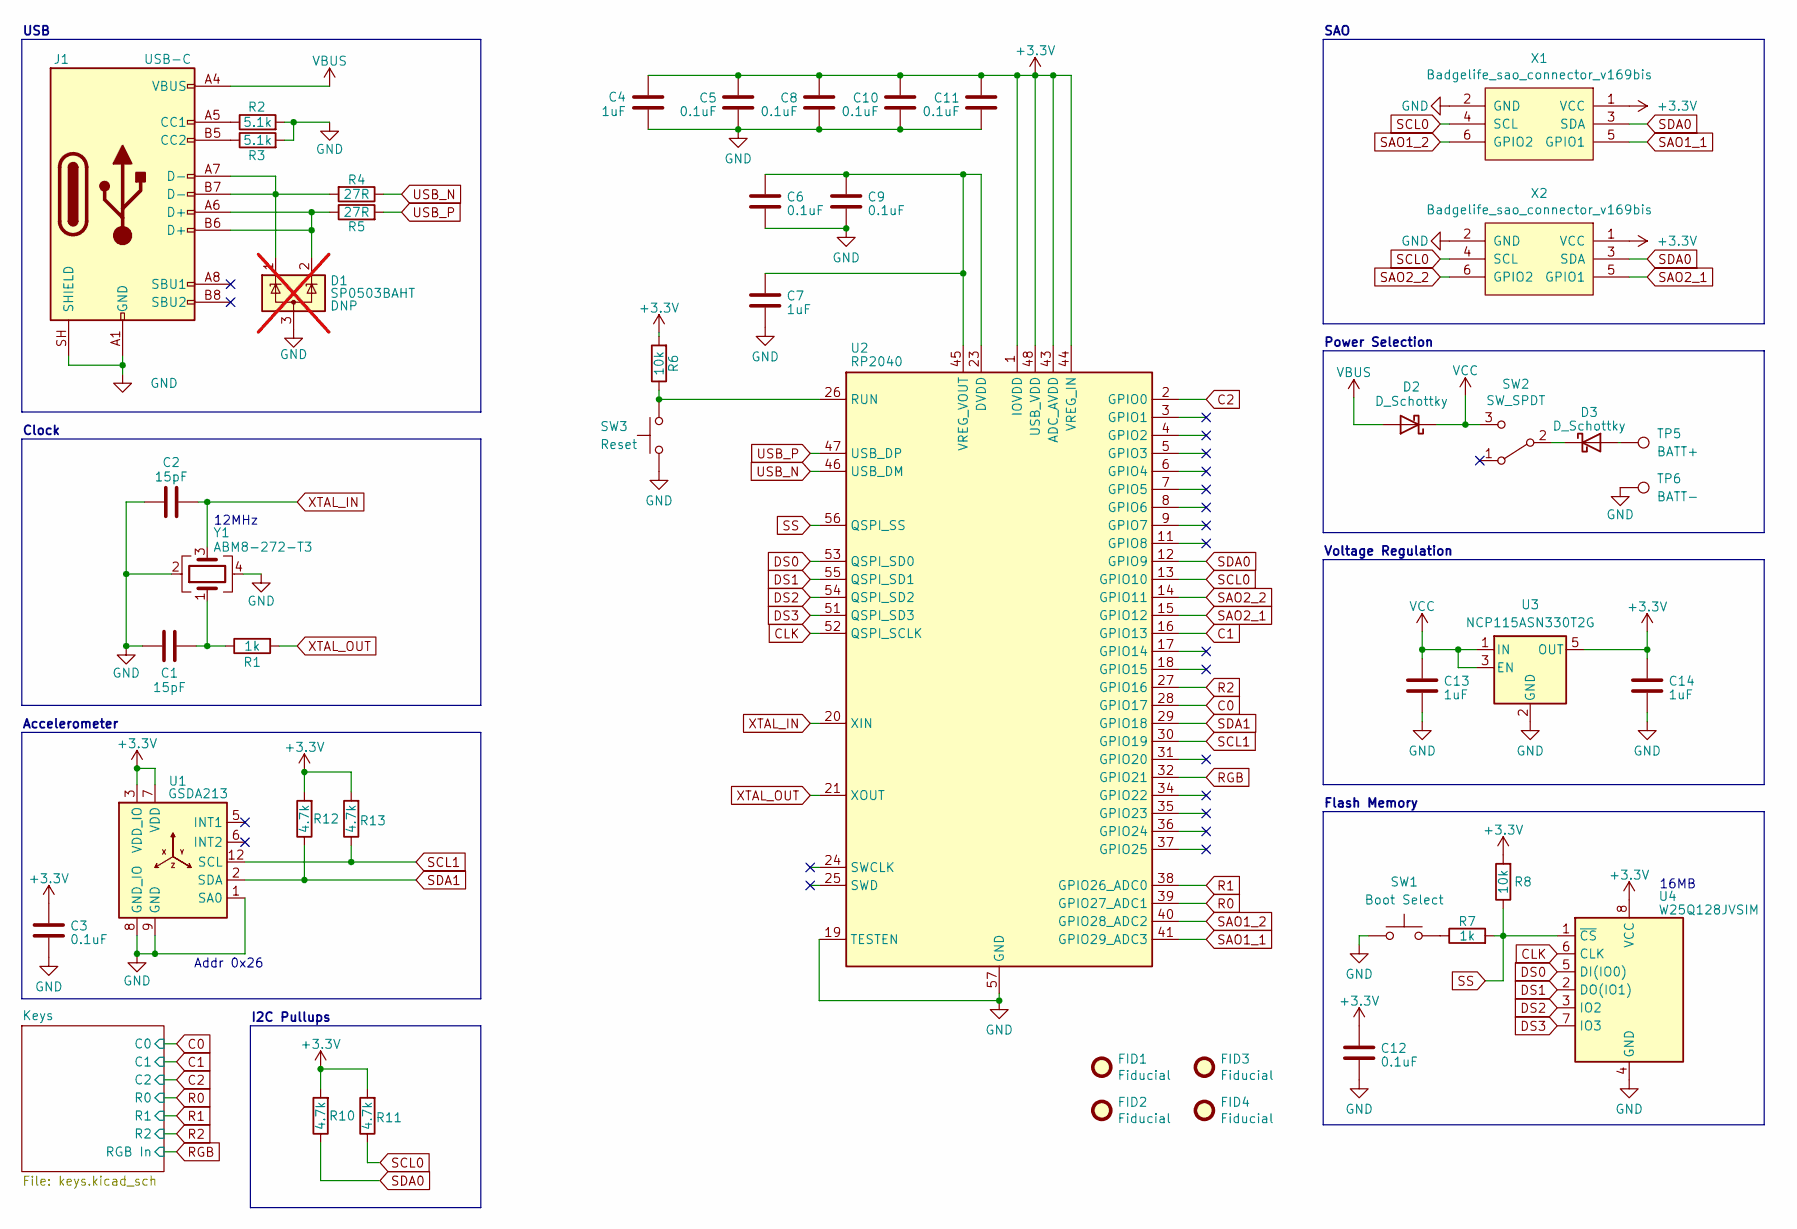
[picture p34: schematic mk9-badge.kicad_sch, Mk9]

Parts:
C1, C2: 15pF; C_0603_1608Metric
C3, C5, C6, C8, C9, C10, C11, C12: 0.1uF; C_0603_1608Metric
C4, C7, C13, C14: 1uF; C_0603_1608Metric
D1: SP0503BAHT; SOT-23-3; not fitted
D2, D3: D_Schottky; D_SOD-123F
FID1, FID2, FID3, FID4: Fiducial; Fiducial_1mm_Mask2mm
J1: USB-C; USB_C_Receptacle_HCTL_HC-TYPE-C-16P-01A
R1, R7: 1k; R_0603_1608Metric
R2, R3: 5.1k; R_0603_1608Metric
R4, R5: 27R; R_0603_1608Metric
R6, R8: 10k; R_0603_1608Metric
R10, R11, R12, R13: 4.7k; R_0603_1608Metric
SW1: Boot Select; SW_SPST_EVQP7C
SW2: SW_SPDT; SW_SPDT_CK-JS102011SAQN
SW3: Reset; SW_SPST_EVQP7C
TP5: BATT+; TestPoint_Pad_2.5x2.5mm
TP6: BATT-; TestPoint_Pad_2.5x2.5mm
U1: GSDA213; Kionix_LGA-12_2x2mm_P0.5mm_LayoutBorder2x4y
U2: RP2040; QFN-56-1EP_7x7mm_P0.4mm_EP3.2x3.2mm
U3: NCP115ASN330T2G; SOT-23-5
U4: W25Q128JVSIM; SOIC-8_5.3x5.3mm_P1.27mm
X1, X2: Badgelife_sao_connector_v169bis; Badgelife-Shitty-v1.69bis
Y1: ABM8-272-T3; Crystal_SMD_Abracon_ABM8G-4Pin_3.2x2.5mm

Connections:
C0: U2.28 (GPIO17); also elsewhere on the board
C1: U2.16 (GPIO13); also elsewhere on the board
C2: U2.2 (GPIO0); also elsewhere on the board
CLK: U2.52 (QSPI_SCLK), U4.6 (CLK)
DS0: U2.53 (QSPI_SD0), U4.5 (DI(IO0))
DS1: U2.55 (QSPI_SD1), U4.2 (DO(IO1))
DS2: U2.54 (QSPI_SD2), U4.3 (IO2)
DS3: U2.51 (QSPI_SD3), U4.7 (IO3)
GND: C1.1, C2.1, C3.1, C4.1, C5.1, C6.1, C7.1, C8.1, C9.1, C10.1, C11.1, C12.1, C13.1, C14.1, D1.3 (A), J1.A1 (GND), J1.A12 (GND), J1.B1 (GND), J1.B12 (GND), J1.SH (SHIELD), R2.2, R3.2, SW1.1, SW3.1, TP6.1 (1_1), U1.1 (SA0), U1.8 (GND_IO), U1.9 (GND), U2.19 (TESTEN), U2.57 (GND), U3.2 (GND), U4.4 (GND), X1.2 (GND), X2.2 (GND), Y1.2, Y1.4; also elsewhere on the board
unnamed: C1.2, R1.1, Y1.1
unnamed: D1.1 (K), J1.A7 (D-), J1.B7 (D-), R4.2
unnamed: D1.2 (K), J1.A6 (D+), J1.B6 (D+), R5.1
unnamed: D3.2 (A), TP5.1 (1_1)
unnamed: D3.1 (K), SW2.2 (B)
unnamed: J1.A5 (CC1), R2.1
unnamed: J1.B5 (CC2), R3.1
unnamed: R7.1, SW1.2
unnamed: R6.1, SW3.2, U2.26 (RUN)
unnamed: C6.2, C7.2, C9.2, U2.23 (DVDD), U2.45 (VREG_VOUT), U2.50 (DVDD)
R0: U2.39 (GPIO27_ADC1); also elsewhere on the board
R1: U2.38 (GPIO26_ADC0); also elsewhere on the board
R2: U2.27 (GPIO16); also elsewhere on the board
RGB: U2.32 (GPIO21); also elsewhere on the board
SAO1_1: U2.41 (GPIO29_ADC3), X1.5 (GPIO1)
SAO1_2: U2.40 (GPIO28_ADC2), X1.6 (GPIO2)
SAO2_1: U2.15 (GPIO12), X2.5 (GPIO1)
SAO2_2: U2.14 (GPIO11), X2.6 (GPIO2)
SCL0: R11.1, U2.13 (GPIO10), X1.4 (SCL), X2.4 (SCL)
SCL1: R13.1, U1.12 (SCL), U2.30 (GPIO19)
SDA0: R10.1, U2.12 (GPIO9), X1.3 (SDA), X2.3 (SDA)
SDA1: R12.1, U1.2 (SDA), U2.29 (GPIO18)
SS: R7.2, R8.1, U2.56 (QSPI_SS), U4.1 (~CS)
USB_N: R4.1, U2.46 (USB_DM)
USB_P: R5.2, U2.47 (USB_DP)
VBUS: D2.2 (A), J1.A4 (VBUS), J1.A9 (VBUS), J1.B4 (VBUS), J1.B9 (VBUS)
XTAL_IN: C2.2, U2.20 (XIN), Y1.3
XTAL_OUT: R1.2, U2.21 (XOUT)

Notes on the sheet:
Addr 0x26
Clock
12MHz
USB
Power Selection
Voltage Regulation
Flash Memory
I2C Pullups
Accelerometer
16MB
SAO

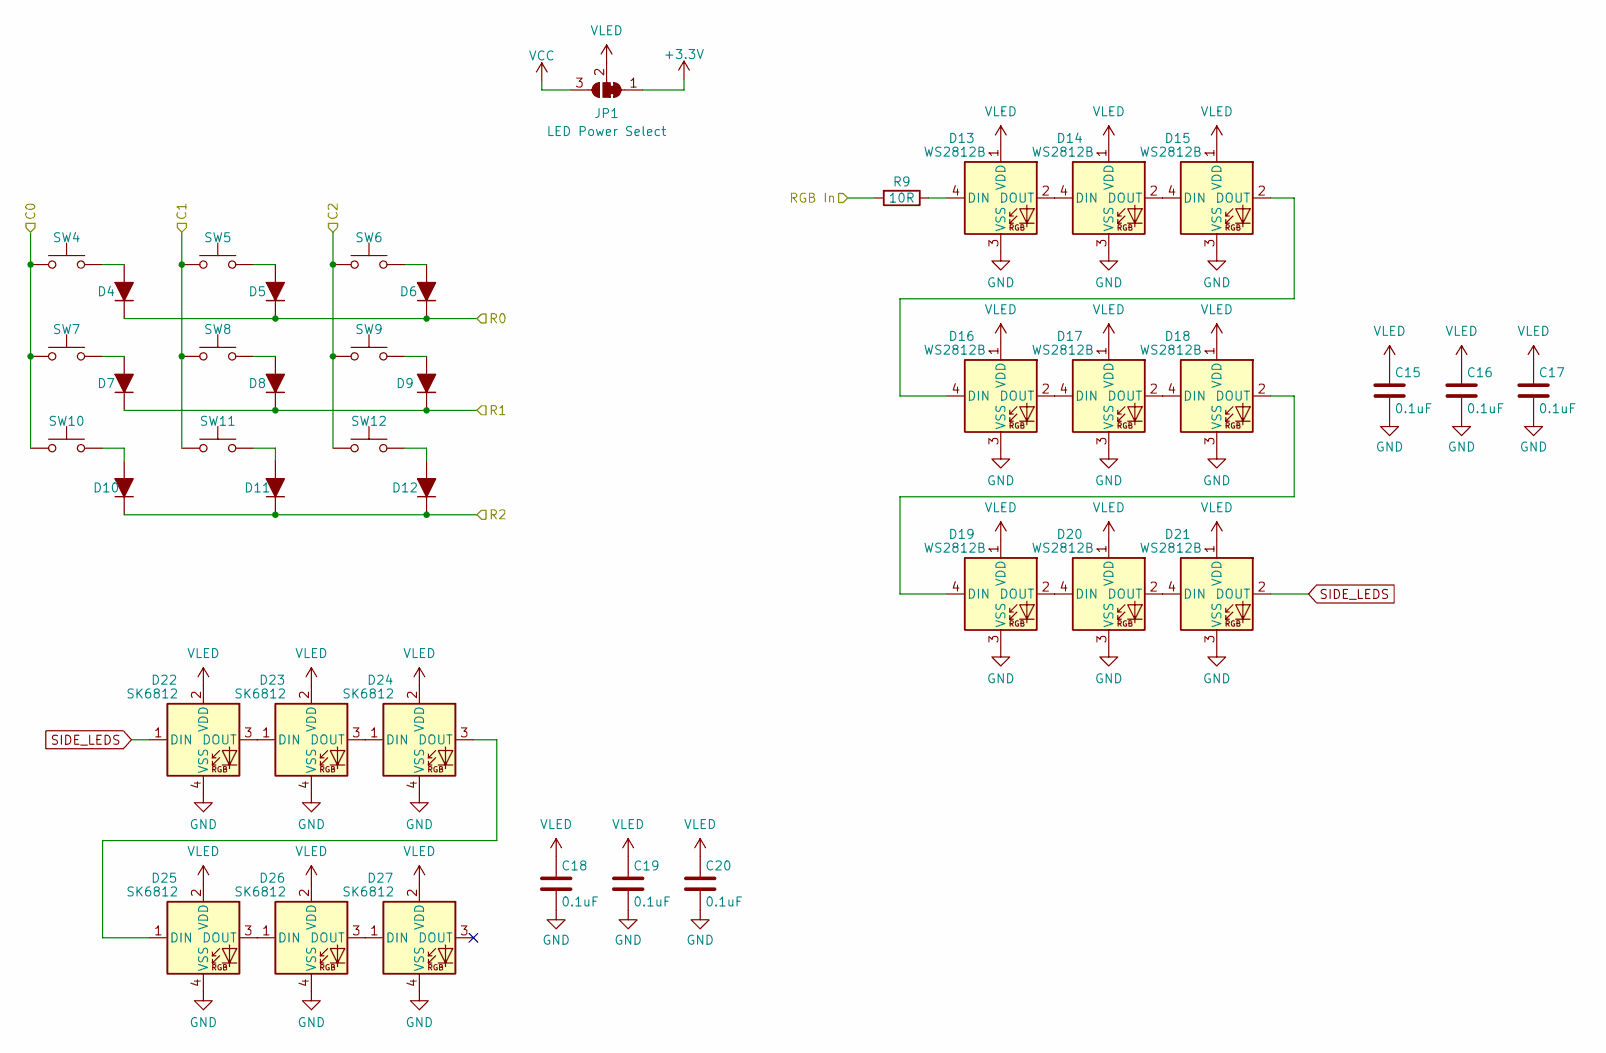
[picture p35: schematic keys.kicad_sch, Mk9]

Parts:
C15, C16, C17, C18, C19, C20: 0.1uF; C_0603_1608Metric
D4, D5, D6, D7, D8, D9, D10, D11, D12: D_Schottky; D_SOD-123F
D13, D14, D15, D16, D17, D18, D19, D20, D21: WS2812B; LED_WS2812B_PLCC4_5.0x5.0mm_P3.2mm_Update
D22, D23, D24, D25, D26, D27: SK6812; LED_SK6812_4020
JP1: LED Power Select; SolderJumper-3_P1.3mm_Bridged2Bar12_RoundedPad1.0x1.5mm
R9: 10R; R_0603_1608Metric
SW4, SW5, SW6, SW7, SW8, SW9, SW10, SW11, SW12: SW_Push; CHERRY_SMDLED_100H

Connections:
C0: SW4.1, SW7.1, SW10.1; also elsewhere on the board
C1: SW5.1, SW8.1, SW11.1; also elsewhere on the board
C2: SW6.1, SW9.1, SW12.1; also elsewhere on the board
GND: C15.2, C16.2, C17.2, C18.2, C19.2, C20.2, D13.3 (VSS), D14.3 (VSS), D15.3 (VSS), D16.3 (VSS), D17.3 (VSS), D18.3 (VSS), D19.3 (VSS), D20.3 (VSS), D21.3 (VSS), D22.4 (VSS), D23.4 (VSS), D24.4 (VSS), D25.4 (VSS), D26.4 (VSS), D27.4 (VSS); also elsewhere on the board
unnamed: D4.2 (A), SW4.2
unnamed: D5.2 (A), SW5.2
unnamed: D6.2 (A), SW6.2
unnamed: D7.2 (A), SW7.2
unnamed: D8.2 (A), SW8.2
unnamed: D9.2 (A), SW9.2
unnamed: D10.2 (A), SW10.2
unnamed: D11.2 (A), SW11.2
unnamed: D12.2 (A), SW12.2
unnamed: D13.4 (DIN), R9.1
unnamed: D13.2 (DOUT), D14.4 (DIN)
unnamed: D14.2 (DOUT), D15.4 (DIN)
unnamed: D15.2 (DOUT), D16.4 (DIN)
unnamed: D16.2 (DOUT), D17.4 (DIN)
unnamed: D17.2 (DOUT), D18.4 (DIN)
unnamed: D18.2 (DOUT), D19.4 (DIN)
unnamed: D19.2 (DOUT), D20.4 (DIN)
unnamed: D20.2 (DOUT), D21.4 (DIN)
unnamed: D22.3 (DOUT), D23.1 (DIN)
unnamed: D23.3 (DOUT), D24.1 (DIN)
unnamed: D24.3 (DOUT), D25.1 (DIN)
unnamed: D25.3 (DOUT), D26.1 (DIN)
unnamed: D26.3 (DOUT), D27.1 (DIN)
R0: D4.1 (K), D5.1 (K), D6.1 (K); also elsewhere on the board
R1: D7.1 (K), D8.1 (K), D9.1 (K); also elsewhere on the board
R2: D10.1 (K), D11.1 (K), D12.1 (K); also elsewhere on the board
RGB: R9.2; also elsewhere on the board
SIDE_LEDS: D21.2 (DOUT), D22.1 (DIN)
VLED: C15.1, C16.1, C17.1, C18.1, C19.1, C20.1, D13.1 (VDD), D14.1 (VDD), D15.1 (VDD), D16.1 (VDD), D17.1 (VDD), D18.1 (VDD), D19.1 (VDD), D20.1 (VDD), D21.1 (VDD), D22.2 (VDD), D23.2 (VDD), D24.2 (VDD), D25.2 (VDD), D26.2 (VDD), D27.2 (VDD), JP1.2 (C)

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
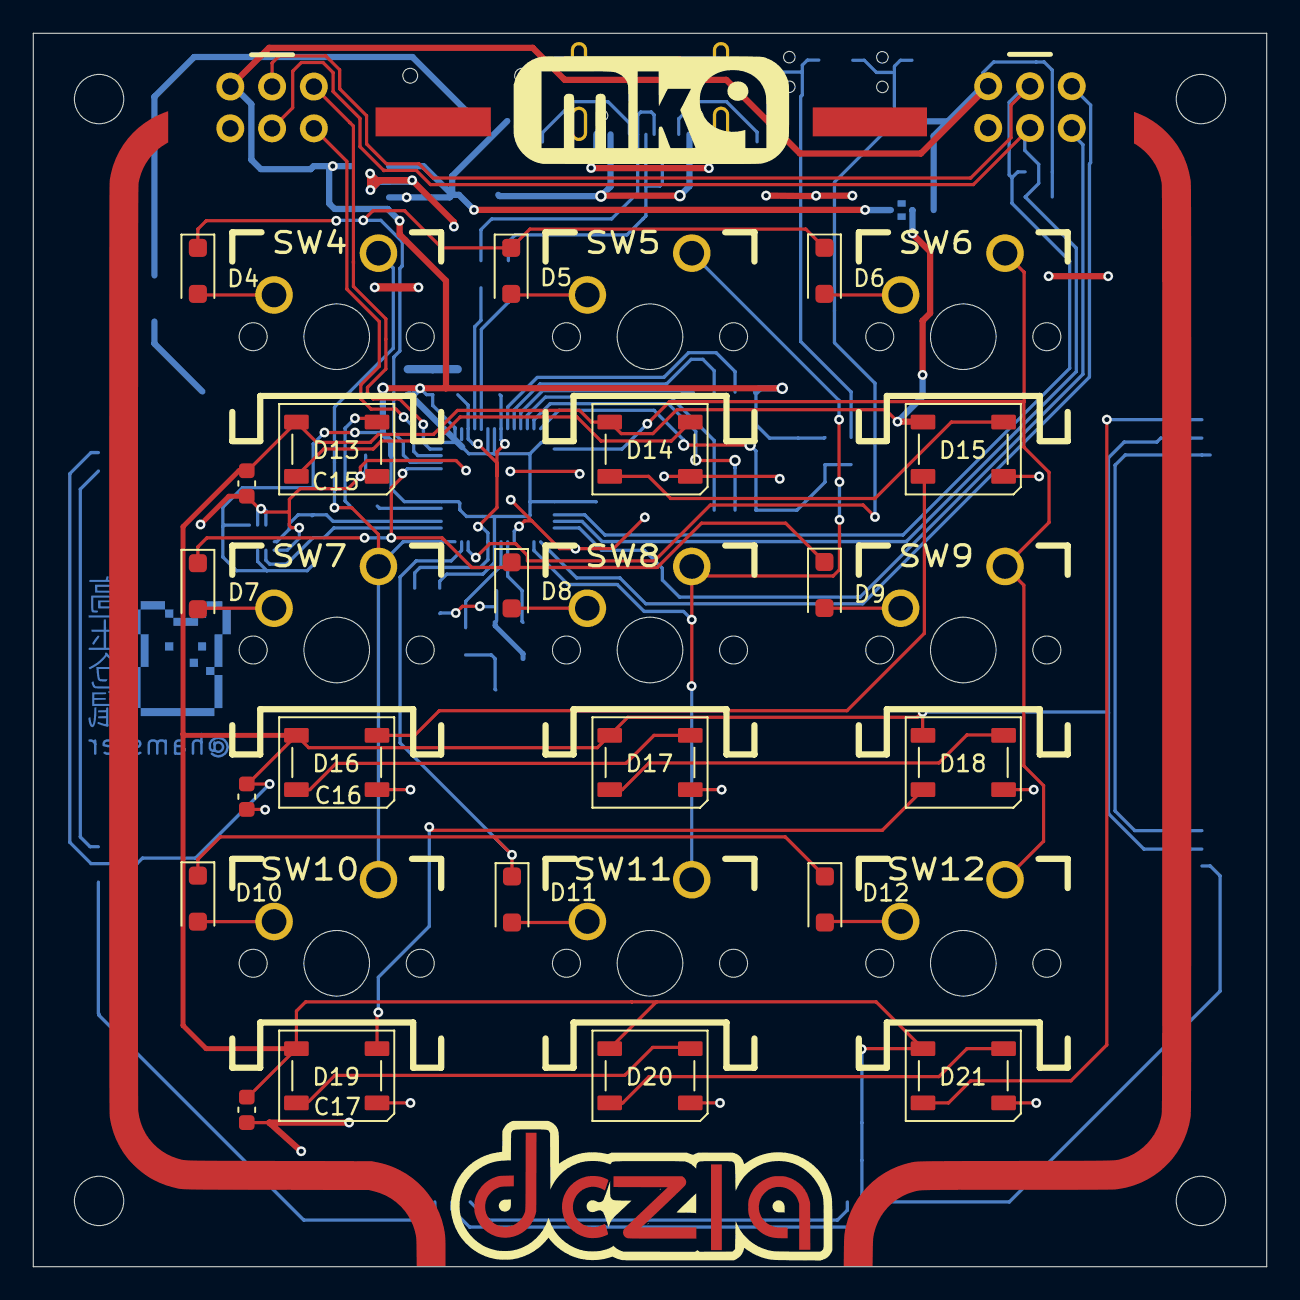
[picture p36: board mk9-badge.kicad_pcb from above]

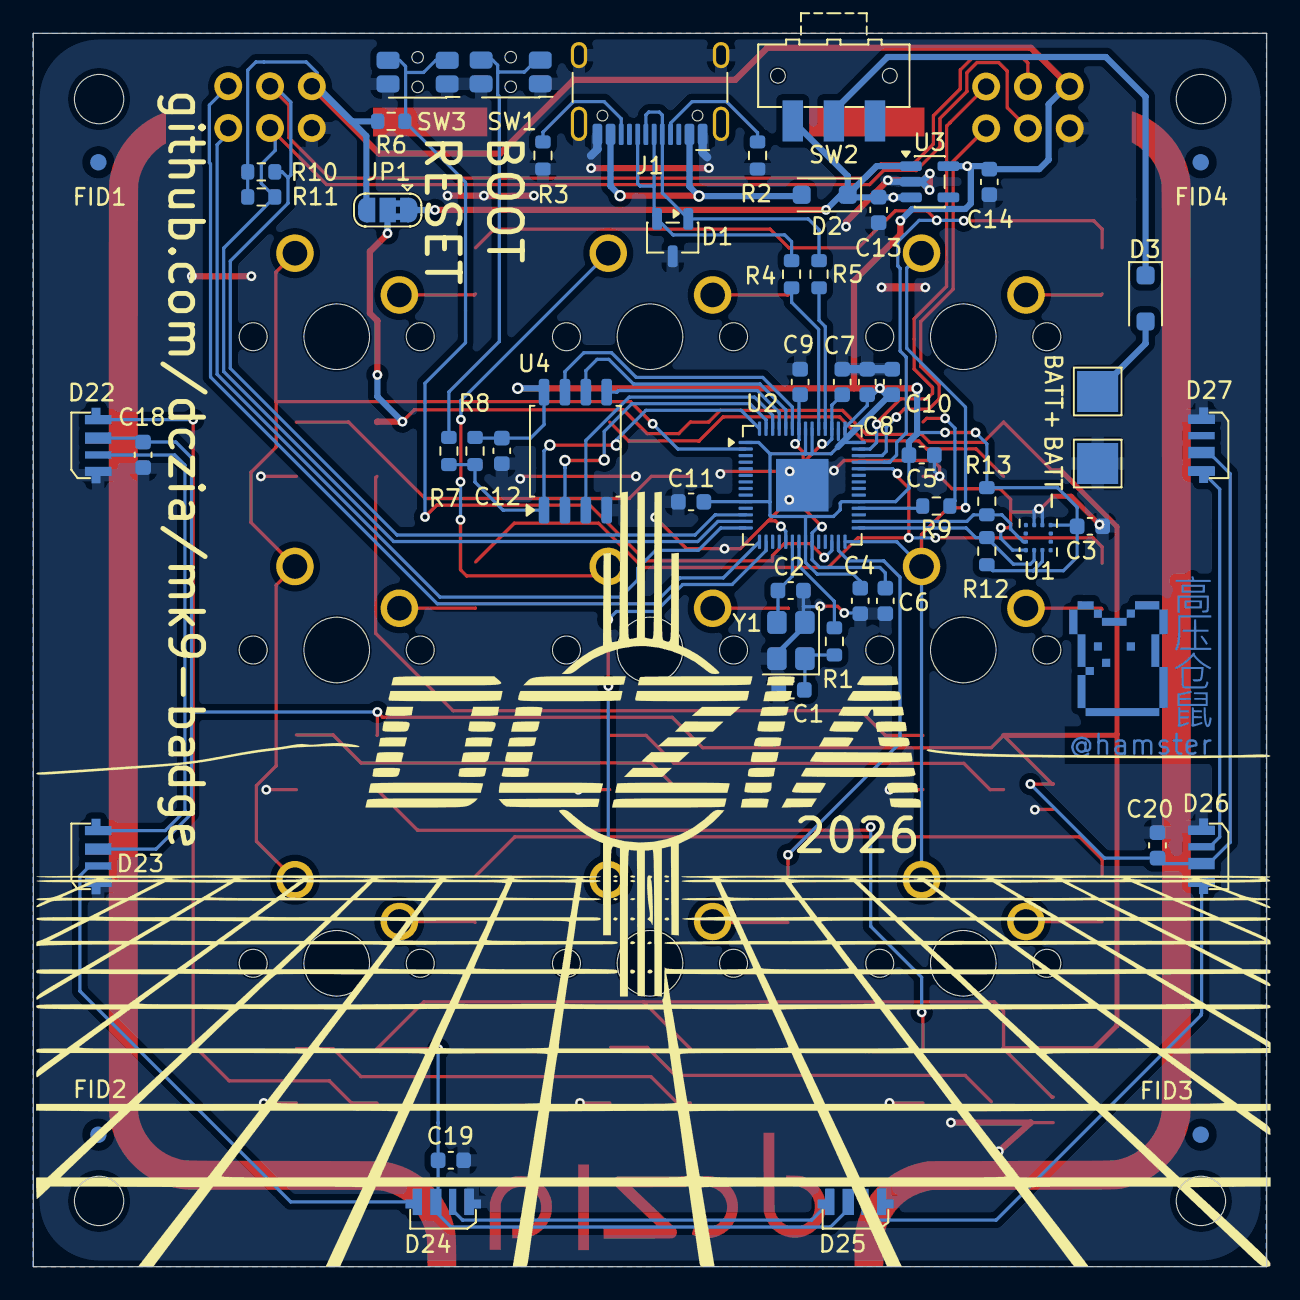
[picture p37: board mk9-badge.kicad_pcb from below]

Board: 2 copper layers, 75.0 x 75.0 mm, 87 parts (55 on the bottom side), 64 nets.

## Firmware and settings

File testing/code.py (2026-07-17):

"""
MK9 Badge Hardware Tester

LED test: all 15 LEDs cycle red → green → blue.
  - Each color holds for 0.5 s, then a wipe sweeps the next color
    across in 0.5 s — 1 second total per color.
  - Tilt the badge on X or Y axis to change the wipe direction.

Key test: press any key to fast-flash that key's LED red → green → blue.
  Held keys are excluded from the background wipe until released.
  All 9 keys can be held simultaneously (NKRO test).

Accelerometer test: tilt X/Y changes the wipe direction live.
  X: negative = tilted left,   positive = tilted right
  Y: negative = top edge down, positive = bottom edge down
  Z: ignored
  The wipe always sweeps toward whichever edge is tilted down.
  Flat → keeps the last direction
"""

import board
import busio
import neopixel
import keypad
import time

# ---------------------------------------------------------------------------
# Hardware
# ---------------------------------------------------------------------------
NUM_PIXELS = 15

pixels = neopixel.NeoPixel(
    board.GP21, NUM_PIXELS,
    brightness=0.5,
    auto_write=False,
    pixel_order=neopixel.GRB,
)

row_pins = (board.GP27, board.GP26, board.GP16)
col_pins = (board.GP17, board.GP13, board.GP0)
keys = keypad.KeyMatrix(row_pins, col_pins, columns_to_anodes=True)

try:
    import adafruit_msa3xx
    _i2c = busio.I2C(board.GP19, board.GP18)
    sensor = adafruit_msa3xx.MSA301(_i2c)
    ACCEL_OK = True
except Exception:
    sensor = None
    ACCEL_OK = False

# ---------------------------------------------------------------------------
# Wipe groups — LED indices ordered by spatial position
#
# Key LED layout (index = row*3 + col):
#   0  1  2       col: 0.0  1.0  2.0
#   3  4  5       row: 0.0  1.0  2.0
#   6  7  8
#
# Backlight LED positions (row, col):
#   9  = (-0.7,  2.7)  top-right
#   10 = ( 1.0,  3.2)  right
#   11 = ( 2.7,  2.7)  bottom-right
#   12 = ( 2.7, -0.7)  bottom-left
#   13 = ( 1.0, -1.2)  left
#   14 = (-0.7, -0.7)  top-left
# ---------------------------------------------------------------------------
_WIPE = {
    'LR': [                     # left → right (col ascending)
        [13, 14, 12],           # left backlights
        [0, 3, 6],              # key col 0
        [1, 4, 7],              # key col 1
        [2, 5, 8],              # key col 2
        [9, 11, 10],            # right backlights
    ],
    'RL': [                     # right → left
        [9, 11, 10],
        [2, 5, 8],
        [1, 4, 7],
        [0, 3, 6],
        [13, 14, 12],
    ],
    'TB': [                     # top → bottom (row ascending)
        [9, 14],                # top backlights
        [0, 1, 2],              # key row 0
        [3, 4, 5, 10, 13],      # key row 1 + side backlights
        [6, 7, 8],              # key row 2
        [11, 12],               # bottom backlights
    ],
    'BT': [                     # bottom → top
        [11, 12],
        [6, 7, 8],
        [3, 4, 5, 10, 13],
        [0, 1, 2],
        [9, 14],
    ],
}

COLORS = [
    (255,   0,   0),   # red
    (  0, 255,   0),   # green
    (  0,   0, 255),   # blue
]

HOLD_TIME      = 0.5          # seconds each color is held solid
WIPE_STEP_TIME = 0.10         # 5 groups × 0.10 s = 0.5 s wipe
FLASH_HALF     = 0.05         # held-key R/G/B flash step time (50 ms/color)
ACCEL_DEAD     = 1.0          # m/s² — below this on both axes = "flat"

# Accelerometer-fault indicator: solid-fill flash, no wipe, all LEDs together.
ERROR_PATTERN = [
    COLORS[0], COLORS[0], COLORS[0], COLORS[2], COLORS[1],   # R R R B G
    COLORS[0], COLORS[0], COLORS[0], COLORS[2], COLORS[1],   # R R R B G
]
ERROR_STEP_TIME = 0.3          # seconds each color in ERROR_PATTERN is held

# ---------------------------------------------------------------------------
# State
# ---------------------------------------------------------------------------
current_color = 0
next_color    = 1
wipe_dir      = 'LR'

# "hold" → all LEDs show current_color; "wipe" → sweeping next_color in
phase       = 'hold'
phase_start = time.monotonic()
wipe_step   = 0

# Per-LED colour buffer (modified as the wipe advances)
led_buf = [COLORS[current_color]] * NUM_PIXELS

key_held       = [False] * 9
key_flash_step = 0            # cycles through COLORS (R -> G -> B) while held
last_flash     = time.monotonic()

error_step       = 0
error_step_start = time.monotonic()
if not ACCEL_OK:
    led_buf = [ERROR_PATTERN[error_step]] * NUM_PIXELS

# ---------------------------------------------------------------------------
# Helpers
# ---------------------------------------------------------------------------

def _mark_accel_failed():
    """Sensor can't be read from / won't respond — switch to the error flash."""
    global ACCEL_OK, error_step, error_step_start
    ACCEL_OK          = False
    error_step        = 0
    error_step_start  = time.monotonic()


def _read_direction():
    """Return 'LR'/'RL'/'TB'/'BT' — wipe sweeps toward whichever edge is tilted
    down — or None if flat/unavailable."""
    if not ACCEL_OK:
        return None
    try:
        raw_x, raw_y, _ = sensor.acceleration
    except Exception:
        _mark_accel_failed()
        return None
    # Sensor is mounted rotated 90° relative to the board: its raw X axis
    # reads the board's top/bottom tilt, and its raw Y axis reads the
    # board's left/right tilt.
    ax, ay = raw_y, -raw_x
    if abs(ax) < ACCEL_DEAD and abs(ay) < ACCEL_DEAD:
        return None
    if abs(ax) >= abs(ay):
        # ax > 0: right edge down -> sweep ends at right (left-to-right)
        # ax < 0: left edge down  -> sweep ends at left  (right-to-left)
        return 'LR' if ax > 0 else 'RL'
    # ay > 0: bottom edge down -> sweep ends at bottom (top-to-bottom)
    # ay < 0: top edge down    -> sweep ends at top    (bottom-to-top)
    return 'TB' if ay > 0 else 'BT'


def _start_wipe():
    """Begin a new wipe: sample accel direction and reset wipe state."""
    global wipe_dir, wipe_step, phase, phase_start
    direction = _read_direction()
    if direction:
        wipe_dir = direction
    wipe_step   = 0
    phase       = 'wipe'
    phase_start = time.monotonic()


def _finish_wipe():
    """Wipe complete: advance colour cycle and enter hold phase."""
    global current_color, next_color, led_buf, phase, phase_start
    current_color = next_color
    next_color    = (next_color + 1) % len(COLORS)
    led_buf       = [COLORS[current_color]] * NUM_PIXELS
    phase         = 'hold'
    phase_start   = time.monotonic()


print("MK9 Badge Hardware Tester booted. Accelerometer OK: {}".format(ACCEL_OK))

# Prime display
pixels.fill(COLORS[current_color])
pixels.show()

last_accel_print = time.monotonic()

# ---------------------------------------------------------------------------
# Main loop
# ---------------------------------------------------------------------------
while True:
    now = time.monotonic()

    # --- Phase logic ---
    if not ACCEL_OK:
        if now - error_step_start >= ERROR_STEP_TIME:
            error_step        = (error_step + 1) % len(ERROR_PATTERN)
            error_step_start  = now
            led_buf           = [ERROR_PATTERN[error_step]] * NUM_PIXELS

    elif phase == 'hold':
        if now - phase_start >= HOLD_TIME:
            _start_wipe()

    elif phase == 'wipe':
        elapsed_in_phase = now - phase_start
        target_step = int(elapsed_in_phase / WIPE_STEP_TIME)

        # Apply any new steps that are due
        while wipe_step <= target_step and wipe_step < len(_WIPE[wipe_dir]):
            for led in _WIPE[wipe_dir][wipe_step]:
                led_buf[led] = COLORS[next_color]
            wipe_step += 1

        if wipe_step >= len(_WIPE[wipe_dir]):
            _finish_wipe()

    # --- Key events ---
    event = keys.events.get()
    if event:
        if event.pressed:
            key_held[event.key_number] = True
            print("key {} down".format(event.key_number))
        elif event.released:
            key_held[event.key_number] = False
            print("key {} up".format(event.key_number))

    # --- Held-key R/G/B flash step ---
    if now - last_flash >= FLASH_HALF:
        key_flash_step = (key_flash_step + 1) % len(COLORS)
        last_flash     = now

    # --- 1 Hz accelerometer print ---
    if now - last_accel_print >= 1.0:
        last_accel_print = now
        if ACCEL_OK:
            try:
                raw_x, raw_y, az = sensor.acceleration
                ax, ay = raw_y, -raw_x  # board-relative: see _read_direction()
                print("accel: x={:.2f} y={:.2f} z={:.2f} m/s^2".format(ax, ay, az))
            except Exception as e:
                print("accel: read error: {}".format(e))
                _mark_accel_failed()
        else:
            print("accel: not available")

    # --- Render ---
    for i in range(NUM_PIXELS):
        pixels[i] = led_buf[i]

    # Overlay: held keys fast-flash R -> G -> B, excluded from the wipe
    for k in range(9):
        if key_held[k]:
            pixels[k] = COLORS[key_flash_step]

    pixels.show()

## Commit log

2026-07-23 Adding SAO Adapter
    [BOM.xlsx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]
2026-08-07 Change software section to MicroPython firmware
    Updated README to reflect MicroPython firmware instead of CircuitPython.
    Added build guide links
